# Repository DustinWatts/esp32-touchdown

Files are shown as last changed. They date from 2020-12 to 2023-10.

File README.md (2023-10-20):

# ESP32 TouchDown






## Where to buy?

Available from:

- Tindie: -> https://www.tindie.com/products/dustinwattsnl/esp32-touchdown/ (Ships from The Netherlands)

- Lectronz -> https://lectronz.com/products/esp32-touchdown (Ships from The Netherlands)

- Eplop Electornics -> https://store.eplop.co.uk/product/esp32touchdown/ (Ships from the UK)

- PCBWay -> https://www.pcbway.com/project/gifts_detail/ESP32_TouchDown.html (Ships from China) 

## FreeTouchDeck

#### Your ESP32 TouchDown comes with FreeTouchDeck pre-installed. Check out this simple start guide: [With FreeTouchDeck pre-installed](https://github.com/DustinWatts/esp32-touchdown/wiki/With-FreeTouchDeck-pre-installed)

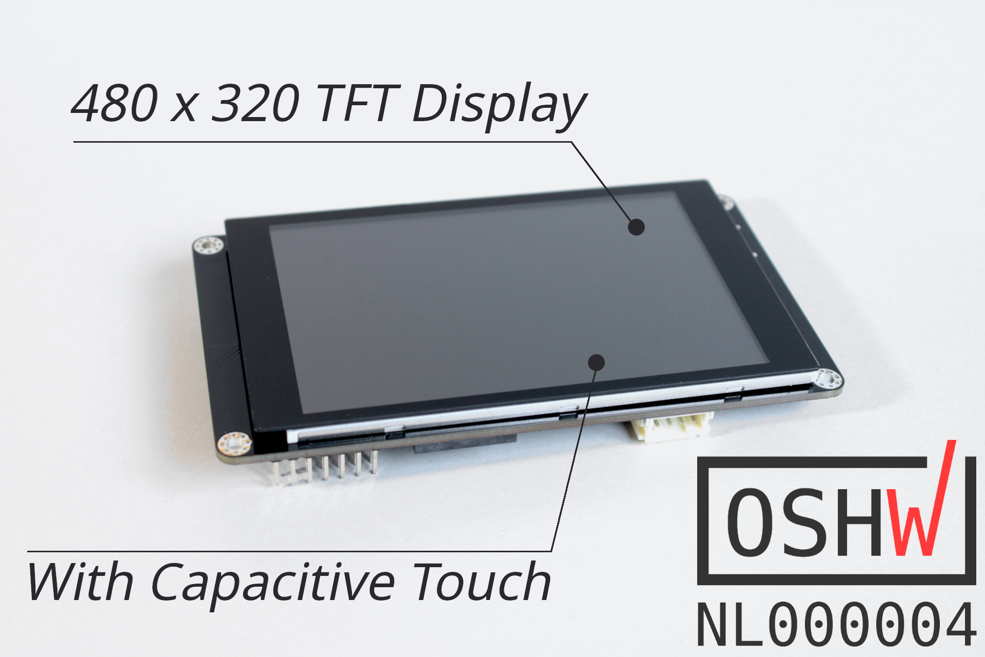
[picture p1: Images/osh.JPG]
ESP32 TouchDown


ESP32 TouchDown

While working on [FreeTouchDeck](https://github.com/DustinWatts/FreeTouchDeck), I really wanted to use capacitive touch. Unfortunately, most modules I could find were resistive touch and capacitive touch has a much nicer user experience. While I was designing, it made sense to put the ESP32 on the board itself, removing the need for an ESP32 Dev board. I wanted to take full advantage of the ESP32 wireless capabilities (Wifi, BLE) so I included a battery management circuit. ESP32 TouchDown can run off of a LiPo battery and also charge it. Here is a full list of the features:

- ESP32-WROOM-32D
- ILI9488 480*320 TFT screen in 4-wire SPI mode
- FT62x6 Capacitive Touch Controller
- APK2112 3.3V regulator _(On V1.1 of the board an AP7365 is used, see changelog.txt)_
- MCP73831 battery management IC _(On V1.1 of the board a Shouding SD8016 is used, see changelog.txt)_
- CP2102 USB-to-UART bridge
- USB-C connector
- microSD card holder
- Battery voltage divider connected to GPIO35
- Passive buzzer connected to GPIO26
- 12 unused GPIO's broken out
- Stemma / JST-PH I2C connector

ESP32 TouchDown works out of the box (as ESP32 Dev Module) with the Arduino IDE, providing you have installed the ESP32 Arduino Core. If you have not, this is where you can find it: [https://github.com/espressif/arduino-esp32](https://github.com/espressif/arduino-esp32).

## Documentation:

Documentation can be found in the [Wiki](https://github.com/DustinWatts/esp32-touchdown/wiki).

## TFT screen and touch controller

ESP32 TouchDown uses an 480x320 screen with an ILI9488 ([datasheet](https://github.com/DustinWatts/esp32-touchdown/blob/main/Hardware/Datasheets/ILITEK_ILI9488.pdf)) driver. There are numerous drivers out there, but I found TFT_eSPI by Bodmer the most versatile. [https://github.com/Bodmer/TFT_eSPI](https://github.com/Bodmer/TFT_eSPI). 

Pins used by the TFT screen are:

- GPIO2 -> DC_RS
- GPIO4 -> TFT_RESET
- GPIO15 -> TFT_CS
- GPIO18 -> SPI Clock
- GPIO23 -> SDI (MOSI)

The TFT backlight anode (positive supply) is selectable via a jumper on the back. You can either power it directly from 3.3V or use GPIO32. By default, the positive source is GPIO32. You can this pin and use PWM to control the backlight brightness.

_Note: On V1.1 of the board the jumpers used are with bridged pads. So by default have no solder blob. See changelog.txt_

TFT Backlight Select

The touch controller is a FocalTech FT62x6 ([datasheet](https://github.com/DustinWatts/esp32-touchdown/blob/main/Hardware/Datasheets/FT6236-FocalTechSystems.pdf)). The first batch uses an FT6236 and the second batch of boards has the FT6206. Both have the same I2C address of 0X38. I made an Arduino IDE library available here: [https://github.com/DustinWatts/FT6236](https://github.com/DustinWatts/FT6236). This library also supports the FT6202.

Pins used by the FT62x6 are:

- GPIO21 -> I2C data
- GPIO22 -> I2C clock
- GPIO27 -> IRQ

## GPIO Breakout

The following GPIO's are broken out on the header:

- GPIO 12
- GPIO 13
- GPIO 14
- GPIO 16
- GPIO 17
- SCK (GPIO 18, used as SPI clock)
- SDO (GPIO 19, used as SPI MOSI)
- SDA (GPIO 21, used as I2C data)
- SCL (GPIO 22, used as I2C clock)
- SDI (GPIO 23, used as SPI MISO)
- GPIO 33
- GPIO 34 (note: INPUT only!)

## SD Card

The following pins are used by the SD card holder:

- GPIO 25 --> CD/DAT3
- GPIO 23 --> CMD
- GPIO 18 --> CLK
- GPIO 19 --> DAT0

*CD (card detect) DAT1 and DAT2 are not connected.*

## Speaker (buzzer)

- GPIO 26

## Uploading code to the ESP32 TouchDown

For FreeTouchDeck installation instructions see: https://github.com/DustinWatts/FreeTouchDeck/wiki/1.-Installation

For other code: The ESP32 TouchDown uses the same configuration as an ESP32 Dev Module. So you can use those board definitions to upload your own code to the ESP32 TouchDown:
Arduino IDE board settings

## Open Source

Everything about the ESP32 TouchDown is open source. This means I provide you will all the designs I make. In this repository, you will find the KiCad project, including schematic, and board layout. Also, the complete BOM is available to you. I have included the datasheets of all the hardware used.

<div style="margin:0 auto;">
  
  <div> 
    License&nbsp;&nbsp;&nbsp;&nbsp;&nbsp;&nbsp;&nbsp;&nbsp;&nbsp;&nbsp;&nbsp;&nbsp;&nbsp;&nbsp;&nbsp;&nbsp;&nbsp;&nbsp;
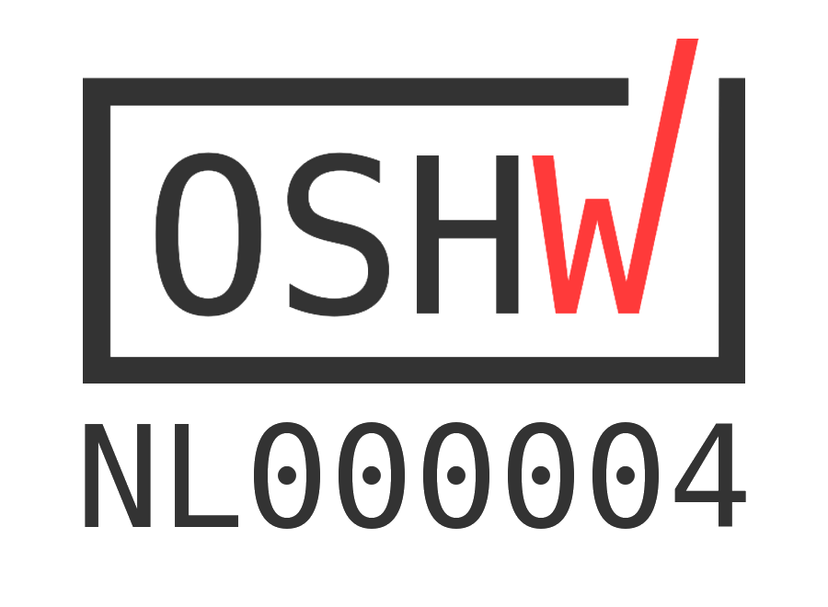
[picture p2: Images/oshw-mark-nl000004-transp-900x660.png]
OSHW
    
  </div>

</div>

## Support Me

If you like what I am doing, there are a number of ways you can support me. 

| Platform | Link|
|:-----:|:-----|
| [Twitter](https://twitter.com/dustinwattsnl "Follow me on Twitter") | You can follow me on Twitter: [@dustinwattsnl](https://twitter.com/dustinwattsnl "Follow me on Twitter")|
| [YouTube](https://www.youtube.com/dustinwatts "Subscrive to my YouTube channel") | You can subscribe to my channel on Youtube: [/dustinWatts](https://www.youtube.com/dustinwatts "Subscribe to my YouTube channel") |
| [Patreon](https://www.patreon.com/dustinwatts) | You can support me by becoming a patron on Patreon: https://www.patreon.com/dustinwatts |
| [PayPal.me](https://www.paypal.me/dustinwattsnl) | You can make a one time donation using PayPal.me: https://www.paypal.me/dustinwattsnl |

## Help

For quick access to help you can join my Discord server where I have a dedicated #esp32-touchdown channel. https://discord.gg/RE3XevS

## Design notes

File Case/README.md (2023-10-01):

# The Case

The case for the ESP32 TouchDown comes in two parts. The front is the same for every style of case you want. The back comes in four variants; a flush cover, a cover with a battery compartment, a back that has the same wedge style as [FreeTouchDeck](https://github.com/DustinWatts/FreeTouchDeck), and a similar style but at an angle of 30°.

You will also find the .f3z file so you can import the case in Fusion360 and modify it to your liking. 
The file called "ESP32_TouchDown_Case_with_Grid.f3z" contains the front with a 2*3 grid.

# The Front
This part is the same for all.
ESP32 TouchDown
(file: ESP32_TouchDown_Front.stl)
# The Flush Back
With four holes for mounting.
ESP32 TouchDown
(file: ESP32_TouchDown_Flush.stl)
# The Battery Back
Which comfortably fits a 2000mAh battery.
ESP32 TouchDown
(file: ESP32_TouchDown_Battery.stl)
# The FreeTouchDeck-style Back
Like the case for FreeTouchDeck.
ESP32 TouchDown
(file: ESP32_TouchDown_FTD.stl)
# The 30° angled FreeTouchDeck-style Back
Like the case for FreeTouchDeck but at an angle of 30°.
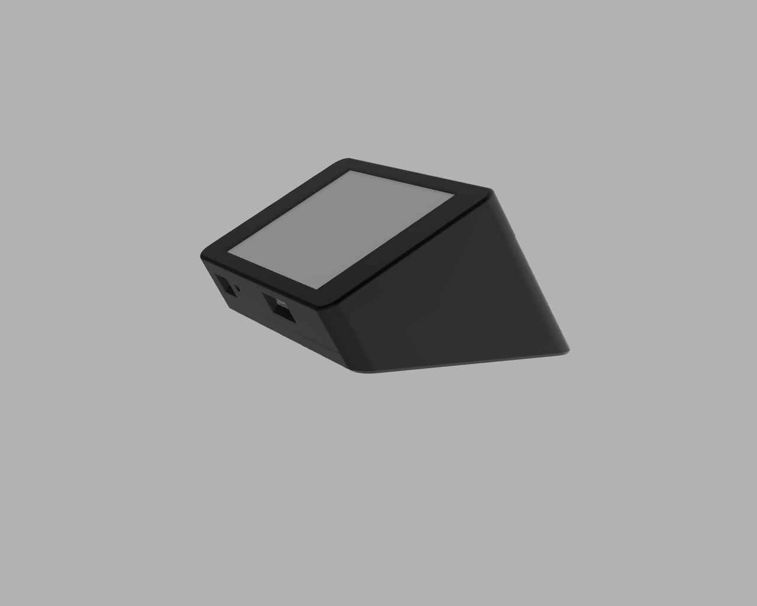
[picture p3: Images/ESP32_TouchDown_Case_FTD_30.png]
ESP32 TouchDown

(file: ESP32_TouchDown_FTD_30.stl)
# The Grid Style Front
A front that has a 2*3 grid.
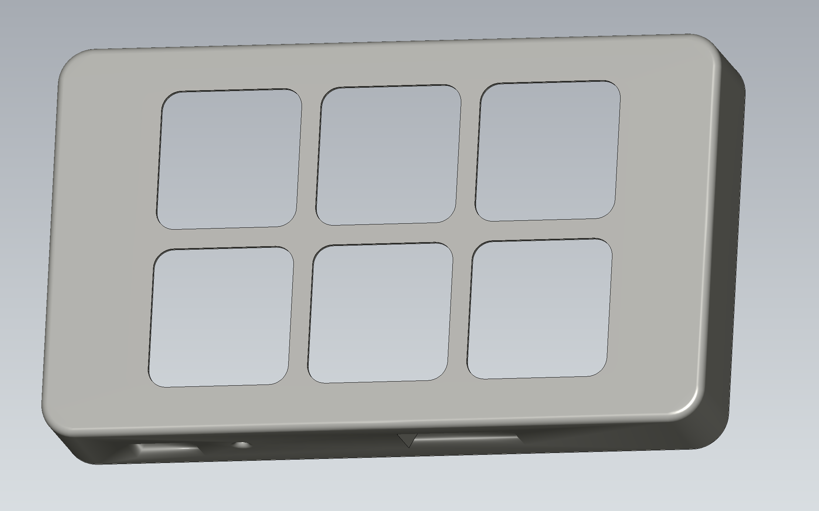
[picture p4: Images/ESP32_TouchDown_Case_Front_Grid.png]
ESP32 TouchDown

(ESP32_TouchDown_Front_Grid.stl)
# More cases on Thingiverse

Also check out the cases made by ESP32 TouchDown users:  https://www.thingiverse.com/search?q=esp32+touchdown

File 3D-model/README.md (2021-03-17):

# ESP32 TouchDown 3D Model

Fusion360 Model, obj and step file to help you design your own case!

### Fusion360 Model:
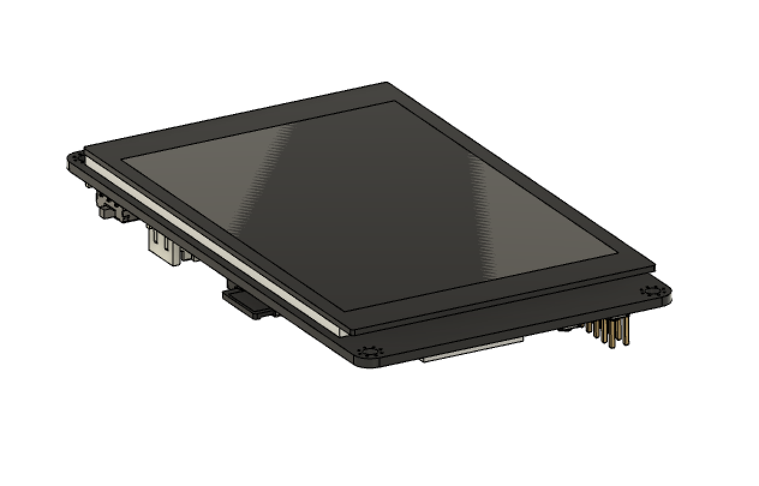
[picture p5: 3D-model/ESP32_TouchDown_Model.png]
ESP32 TouchDown 3D Model


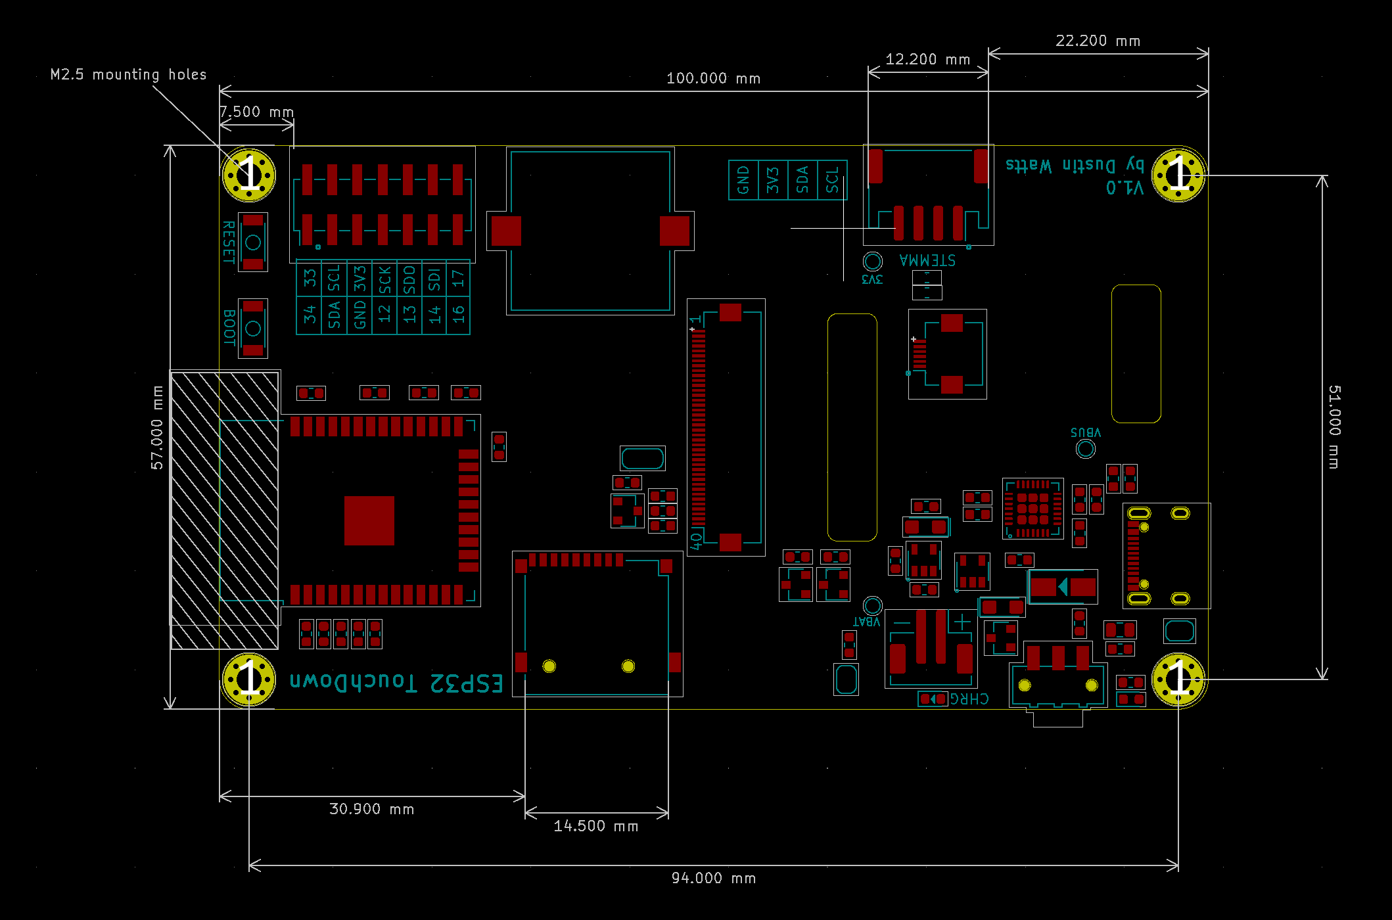
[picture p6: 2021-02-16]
Hardware/ESP32_TouchDown_dimensions.png

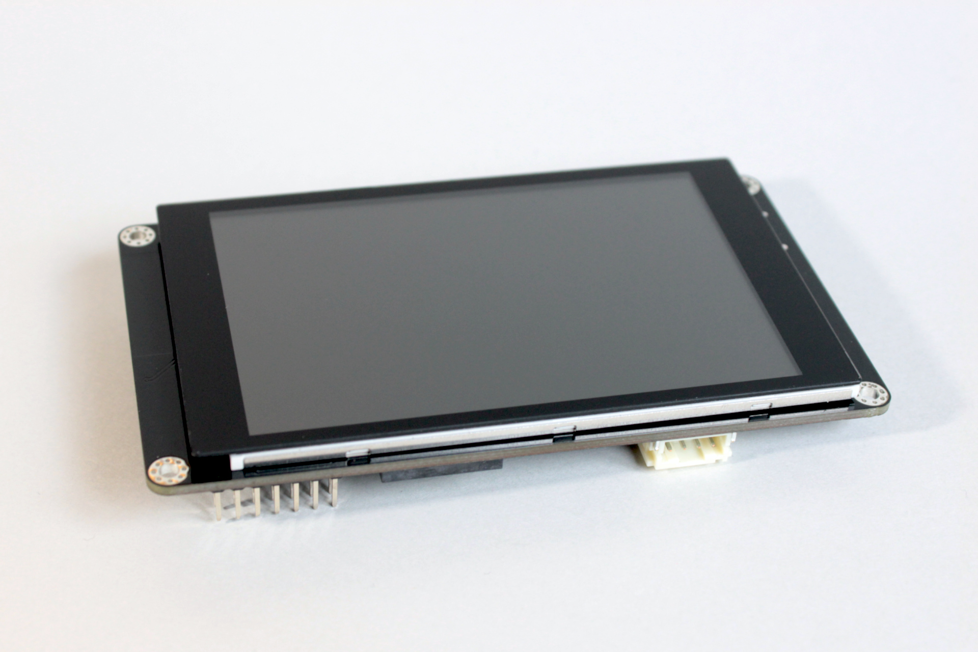
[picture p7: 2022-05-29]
Images/no_overlay.JPG

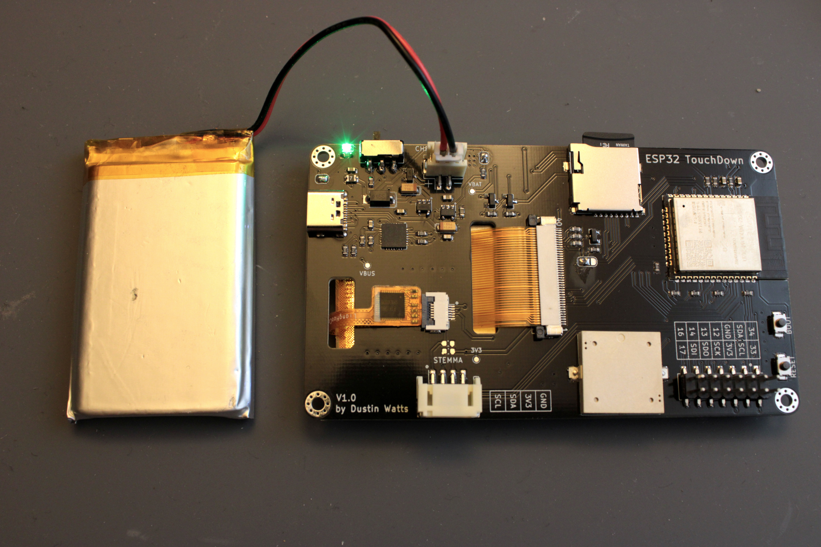
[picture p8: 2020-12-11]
Images/ESP32_TouchDown_1.jpg

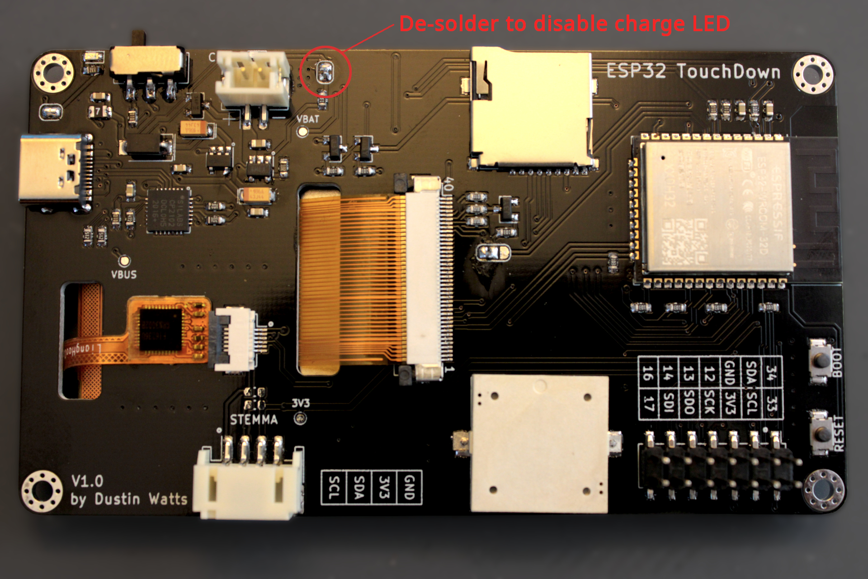
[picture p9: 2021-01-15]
Images/ESP32_TouchDown_Charge_LED.jpg

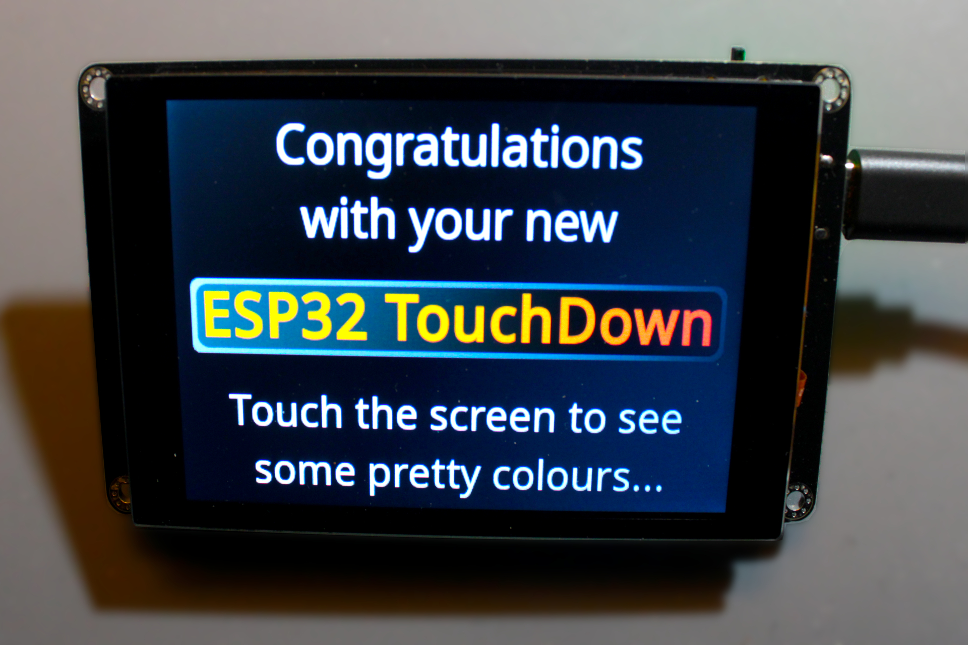
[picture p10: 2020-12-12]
Images/ESP32_TouchDown_2.jpg

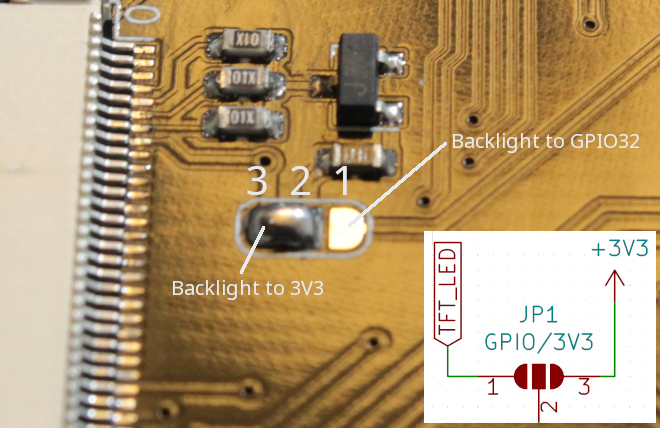
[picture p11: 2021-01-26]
Images/TFT_Backlight_select.jpg

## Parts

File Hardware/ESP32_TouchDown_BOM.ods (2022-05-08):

Item Nr. | Quantity | Ref** | Value | Footprint | Nr. Pads | Manufacturer | Manufacture Part Number | Description | LCSC Part Number
1 | 1 | U4 | * | SMD-38 | 38 | Espressif | ESP32-WROOM-32D | ESP32 | C473012
2 | 1 | U1 | * | QFN-28 5x5x05P | 28 | Silicon Labs | CP2102-GMR | USB to Serial IC | C6568
3 | 1 | F1 | 1.5A 200ms | 0805 | 28 | Littelfuse | 0805L075WR | PTC Fuse | C151146
4 | 1 | U5 | * | SOT-23-5 | 5 | Microchip Technology | MCP73831T-2ACI/OT | LiPo Charging IC | C424093
5 | 1 | U3 | * | SOT-23-5 | 5 | Diodes Inc. | AP2112K-3.3TRG1 | 3.3V regulator | C51118
6 | 1 | SD1 | * | SMD | 13 | Korean Hroparts Elec | TF-01A | microSD card holder | C91145
7 | 3 | Q1, Q2, Q4 | * | SOT-23-3 | 3 | LGE | S8050 | NPN Transistor | C402279
8 | 1 | SW3 | * | SMD | 3 | Korean Hroparts Elec | K3-1280S-F1 | On/Off Slide Switch | C92658
9 | 1 | Q3 | * | SOT-23-3 | 3 | Diodes Inc. | DMG3415U-7 | VBUS/VBATT PNP MOSFET | C96616
10 | 1 | FPC2 | * | P=0.5mm | 8 | JUSHUO | AFC01-S06FCC-00 | FPC Connector for CTC (Bottom Contact) | C262262
11 | 1 | FPC1 | * | P=0.5mm | 42 | JUSHUO | AFC07-S40ECC-00 | FPC Connector for TFT (Top Contact) | C11097
12 | 1 | J5 | * | SMT | 12 | XKB Connectivity | U262-16XN-4BVC11 | USB-C Connector | C319148
13 | 1 | J3 | * | SMD, P=2mm | 42 | JST | B2B-PH-SM4-TB(LF)(SN) | Battery Connector | C160352
14 | 2 | SW1, SW2 | * | SMD, 3x4x2.5mm | 2 | SHOU HAN | TS-1088R-02526 | Tactile button | C455281
15 | 1 | D1 | * | SMA(DO-214AC) | 2 | ST(Semtech) | SS14D | Schottky Diode | C83912
16 | 2 | C4,C5 | 10uF | 3216 | 2 | AVX | TAJA106K010RNJ | 10uF 3216 Tantalum Capacitor | C7177
17 | 1 | LS1 | * | SMD, 16x16x2.5mm | 2 | INGHAi | GSC1625YB-3V4000 | Piezo buzzer | C255335
18 | 1 | J4 | * | SMD, P=2mm | 6 | JST | S4B-PH-SM4-TB(LF)(SN) | Stemma Connector | C265102
19 | 1 | J2 | * | SMD, P=2.54mm | 14 | BOOMELE(Boom Precision Elec) | C84004 | Pin Header 2x7 SMD | C84004
20 | 5 | C1, C2, C6, C8, C10 | 100nF | 0603 | 2 | Jelly Bean | n/a | 0.1uF Ceramic Capacitor
21 | 1 | C7 | 1uF | 0603 | 2 | Jelly Bean | n/a | 1uF Ceramic Capacitor
22 | 1 | C9 | 10uF | 0603 | 2 | Jelly Bean | n/a | 10uF Ceramic Capacitor
23 | 1 | R13 | 1.3K | 0603 | 2 | Jelly Bean | n/a | 1.3K 0603 Resistor
24 | 2 | R3, R4 | 1K | 0603 | 2 | Jelly Bean | n/a | 1K 0603 Resistor
25 | 2 | Rprog1, R22 | 3.3K | 0603 | 2 | Jelly Bean | n/a | 3.3K 0603 Resistor
26 | 1 | R1 | 4.7K | 0603 | 2 | Jelly Bean | n/a | 4.7K 0606 Resistor
27 | 9 | R5, R6, R7, R8, R10, R11, R12, R18, R23 | 10K | 0603 | 2 | Jelly Bean | n/a | 10K 0603 Resistor
28 | 2 | R24, R25 | 5.1K | 0603 | 2 | Jelly Bean | n/a | 5.1K 0603 Resistor
29 | 4 | R2, R9, R14, R15 | 100K | 0603 | 2 | Jelly Bean | n/a | 100K 0603 Resistor
30 | 1 | D3 | Blue, Vf=3.2V | 0603 | 2 | Jelly Bean | n/a | 0603 LED Blue
31 | 1 | D2 | Green, Vf=2.8V | 0603 | 2 | Jelly Bean | n/a | 0603 LED Green
 | Alternate parts
 |  | Q3 | * | SOT-23-3 | 3 | PJSEMI | PJM3415PSA | VBUS/VBATT PNP MOSFET | C411717
 |  | LS1 | * | SMD, 16x16x2.5mm | 2 | KELIKING | KLJ-1625 | Piezo buzzer | C201041
 |  | U3 | * | SOT-23-5 | 5 | Diodes Inc. | AP7365-33WG-7 | 3.3V regulator | C150742
 |  | U5 | * | SOT-23-5 | 6 | Shouding | SD8016 | LiPo Charging IC | C250808
 |  | Total number SMD pads | 282
 |  | Total number TH pads | 4

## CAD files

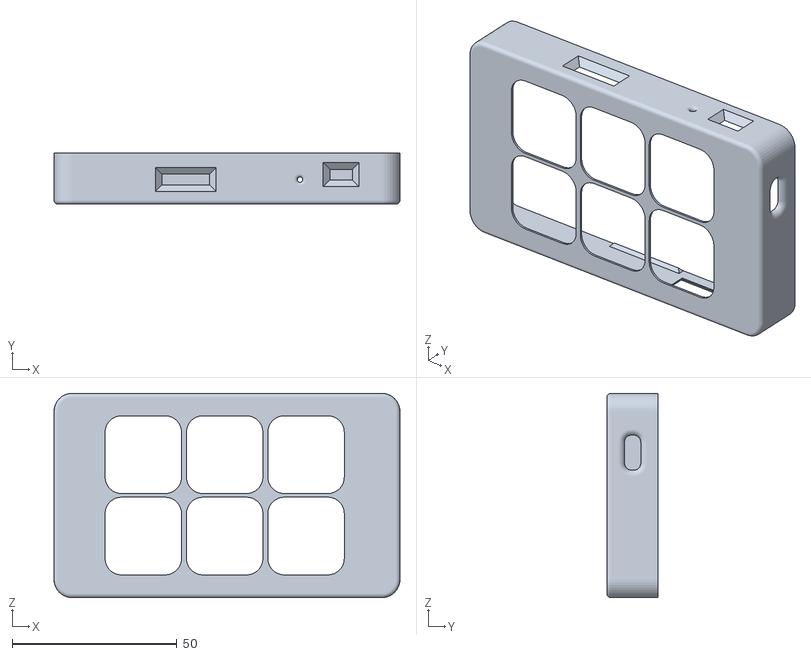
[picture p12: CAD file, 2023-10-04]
Case/ESP32_TouchDown_Front_Grid.stl
105.0 x 15.6 x 62.0

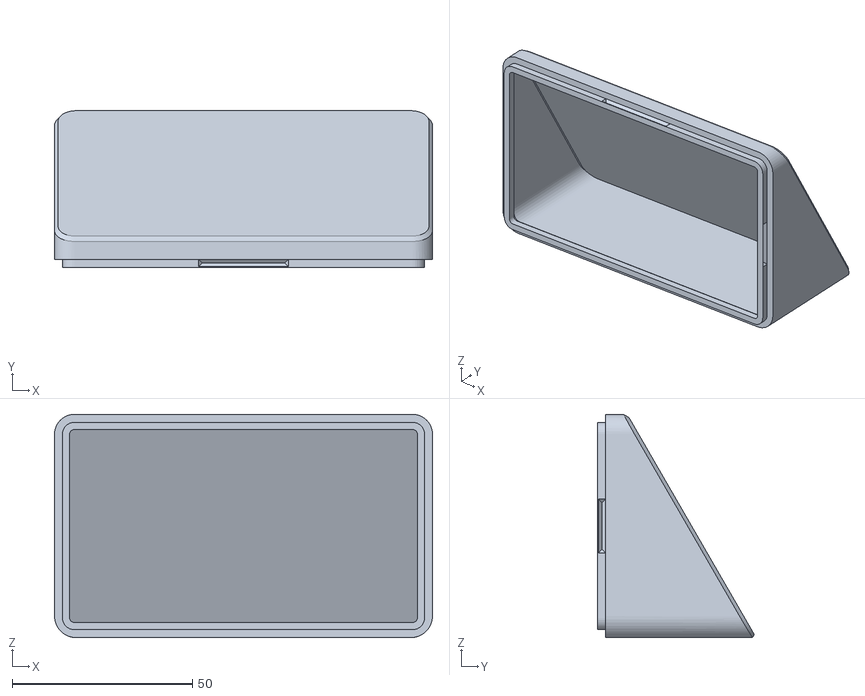
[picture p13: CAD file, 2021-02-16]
Case/ESP32_TouchDown_Back_FTD_30.stl
105.0 x 43.5 x 62.0

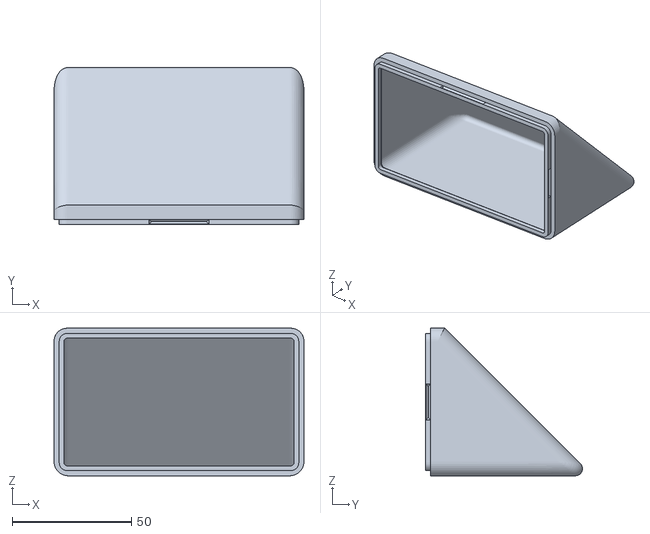
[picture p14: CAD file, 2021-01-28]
Case/ESP32_TouchDown_Back_FTD.stl
105.0 x 65.9 x 62.0

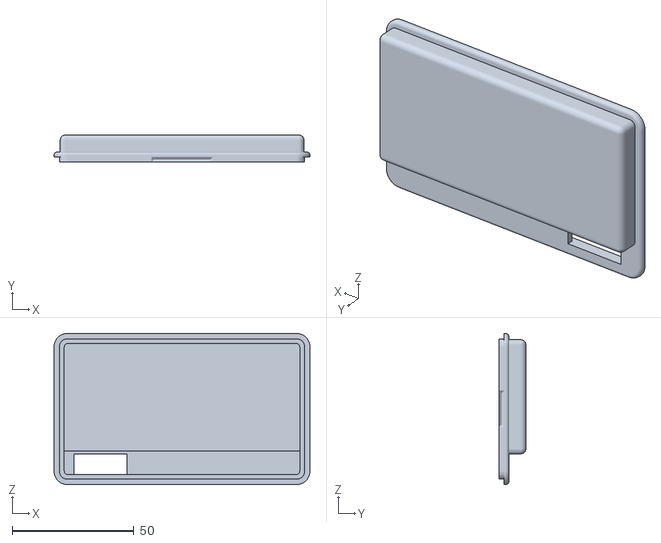
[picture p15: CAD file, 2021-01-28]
Case/ESP32_TouchDown_Back_Battery.stl
105.0 x 11.0 x 62.0

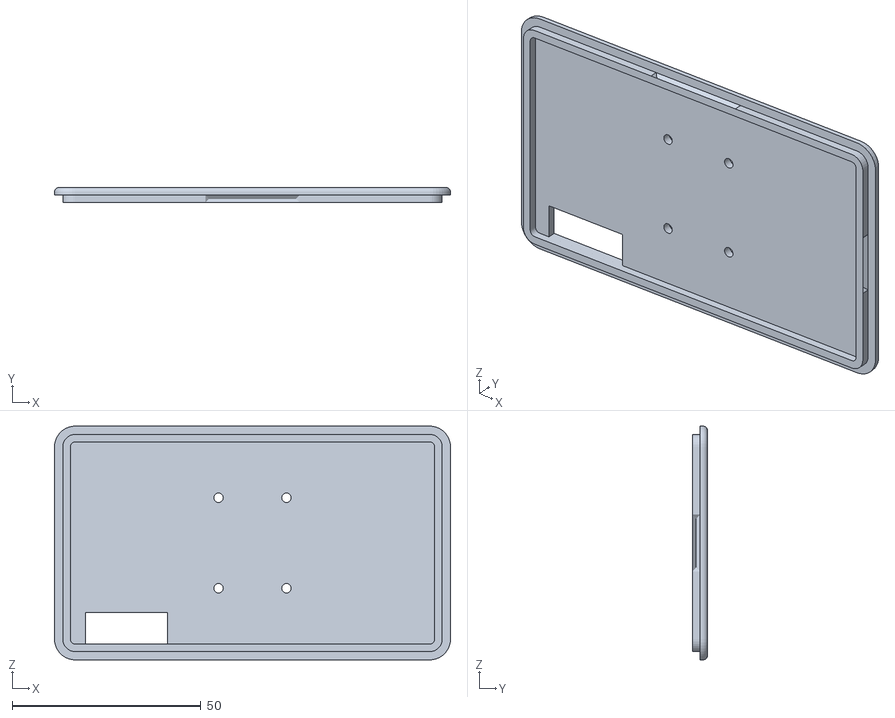
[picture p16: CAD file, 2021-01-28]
Case/ESP32_TouchDown_Back_Flush.stl
105.0 x 4.00 x 62.0

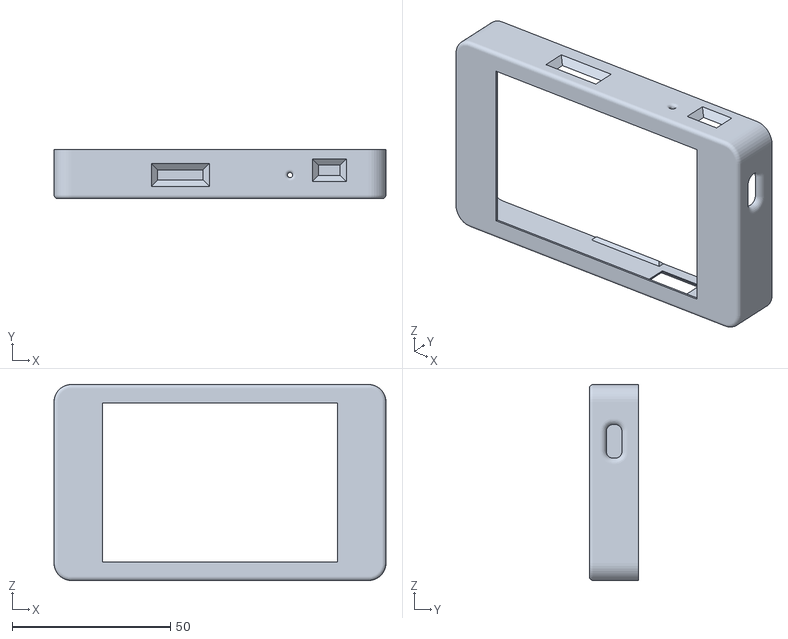
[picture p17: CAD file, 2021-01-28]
Case/ESP32_TouchDown_Front.stl
105.0 x 15.6 x 62.0

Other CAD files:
3D-model/ESP32_TouchDown_Model.f3d

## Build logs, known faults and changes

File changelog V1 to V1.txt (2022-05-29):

ChangeLog

ESP32 TouchDown V1.0 VS ESP32 TouchDown V1.1

- Changed Jumpers to pre-bridged pads (connected without solderblob)
	So if you want to disable the ON and CHARGE LED, you will have to cut the trace and if you want to change the TFT backlight from GPIO32 to fixed 3.3V you will have to cut the trace and put a solderblob from the middle pad to the other pad.

- MCP73831 Battery management IC changed to Shouding SD8016 (pin compatible)
- AP2112K Voltage regulator changed to AP7365 (pin compatible)

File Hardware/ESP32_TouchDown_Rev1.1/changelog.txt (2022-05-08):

Changelog ESP32 TouchDown

Rev 1.1

- Changed Jumpers to pre-bridged pads (connected without solderblob)

- MCP73831 Battery management IC changed to Shouding SD8016 (pin compatible)

- AP2112K Voltage regulator changed to AP7365 (pin compatible)

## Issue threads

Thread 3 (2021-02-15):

Where to buy aka Crowdfunding?

JanHBade, 2021-02-15:
Hello,

are they any plans to make a batch of full function pcbs? or a crowdfunding project?

Not everyone have the skill to make a one board?

fwahl711, 2021-02-15:
would be interested as well. maybe tindie?

DustinWatts, 2021-02-15:
Hi @JanHBade The idea is for me to sell them on Tindie indeed. Hackaday was a bit early with discovering the ESP32 TouchDown. I made a batch and sold them to a few people to get some feedback. I'm currently working on a batch to put up on Tindie, I hope later this week!

fwahl711, 2021-02-15:
hey @DustinWatts thanks for the fast reply! looking forward to it :) On the upside of early discovery, you can probably make 10-20x of what u planned originally ...

glennswest, 2021-02-15:
I would love to use these to make cnc countroller. Let me know and I will buy a few.

K1rdro, 2021-02-15:
I'd like to buy a couple as well, depending on the price.

danielo515, 2021-02-17:
Another interested here

DustinWatts, 2021-02-17:
Yesterday I put the Tindie listing up. https://www.tindie.com/products/dustinwattsnl/esp32-touchdown/

It seems I highly underestimated interest and it sold out within 10 minutes. Off course I am making more, but to get a bit of an idea of how many more to make, you can join the waitlist.

danielo515, 2021-02-17:
Thanks for the link. Joined!

On Wed, Feb 17, 2021 at 7:19 AM Dustin Watts <notifications@github.com>
wrote:

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

--
---
https://danielorodriguez.com

Closed 2021-07-03.

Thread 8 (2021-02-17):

Please add BOM entry for the TFT

zapta, 2021-02-17:
Thanks for sharing your design.  I couldn't find the TFT you are using in the BOM. Can you please add it with model number or a link to a vendor?

(By TFT I mean the entire TFT subassembly, not just the TFT or touch controller ICs).

Thanks.

hagbardZ, 2021-03-11:
The same problem here ... couldnt find the TFT :-(
Could you please add a link, where to find it ?

DustinWatts, 2021-03-15:
Hi @zapta and @hagbardZ sorry for the late reaction. The screens are sold under all kinds of part numbers. But I did find them on AliExpress, if you search for "ILI9488 ft6236" you can find them. I wish I could make it easier and give you a part number but it takes some searching.

Make sure the pinout described matches that of the FPC connector of the screen and touch controller:
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

There are two types. One with a short flex PCB with the touch controller and one with a long one. You will need the one with the SHORT flex PCB:

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

Closed 2021-07-03.

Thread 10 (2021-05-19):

Case models in STEP format?

Snowflake6, 2021-05-19:
Is there any chance the case models could be posted in STEP or IGES or perhaps Solidworks native format?

(Solidworks doesn't like working with STL files.)  It's not a showstopper to have to start from scratch but it would be nice to have a starting point for designing a new case.

DustinWatts, 2021-07-03:
https://github.com/DustinWatts/esp32-touchdown/tree/main/3D-model Contains a .step model of the ESP32 TouchDown

Closed 2021-07-03.

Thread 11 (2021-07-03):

Battery recomendations

pjratl, 2021-07-03:
any suggested battery and or wiring?

DustinWatts, 2021-07-03:
Hi @pjratl any protected single cell LiPo (3.7V) will work. As to wiring, the ESP32 TouchDown uses a JST-PH (2.0mm pitch) connector. The + and - are marked on the board, so make sure that matches you battery. Make sure you don't plug in the battery with a reversed polarity! If you battery comes with the wrong polarity, you can swap the pins on the battery connector by pulling the pins out and putting them back in the header in the correct orientation.

As to capacity, I recommend getting at least 2000mAh. This will give you about 10 hours of continues use. More off course if you use the sleep function.

rastagraffix, 2022-07-01:
What size is the cutout in the battery back? It would be helpful to mention this in the README.

DustinWatts, 2022-07-02:
> What size is the cutout in the battery back? It would be helpful to mention this in the README.

At around 3.55V/3.6V (depending on V1.0 or V1.1 of the ESP32 TouchDown) the voltage regulator stops regulating down to 3.3V. There will still be output an output voltage on the LDO but it will be unregulated. This also depends on the current draw. With a lower current draw the dropout of the regulator is lower.

The ESP32 will operate (according to the datasheet) with a minimum of 3.0V. To be on the safe side, I recommend a minimum battery voltage of 3.6V that will make sure the ESP32 TouchDown works according to what is expected.

rastagraffix, 2022-07-02:
No, I was asking what the physical size of the battery cutout is.

DustinWatts, 2022-07-03:
Ah... I confused cutout with cutoff :)

It is 95 x 43 mm.

DustinWatts, 2022-12-20:
@danielo515 Thanks for sharing!

DustinWatts, 2023-03-15:
I will edit the README.md to reflect the size of the battery compartment on the battery case, and will add some information that will inform people that any single cell LiPo with a protection circuit will work. But it is very important to check that the polarity of the battery connector matches that of the connector on the board!

Closed 2023-03-15.

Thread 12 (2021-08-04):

FLASH from PlatformIO requires BOOT+RESET buttons?

bradanlane, 2021-08-04:
I am trying to load new firmware to the Touchdown using PlatformIO. I have not tested with Arduino IDE.

The only way I can get it to flash is to use the BOOT and RESET buttons. Is this normal / expected ?

DustinWatts, 2021-08-05:
Technically there is an auto-reset circuit that should do it for you. But the BOOT and RESET buttons are there so you can also do it manually.

All ESP32 TouchDown that are sent out are tested with the AUTO RESET function so maybe it is something in PlatformIO?

bradanlane, 2021-08-05:
The BOOT button was broken on my unit and I replaced it. This button now works (which is good since I must always use it). I do not believe there is any difference in the way PlatformIO operates. I will attempt to test the behavior of the "auto reset" circuit.

DustinWatts, 2022-05-08:
This has been stale for a while, so I'm closing it.

Closed 2022-05-08.

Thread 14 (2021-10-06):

KiCad footprints folder is incomplete

OhmSchool, 2021-10-06:
Hi there,
Fantastic project!  Due to worldwide product shortages, I would like to replace several hardware components and print a customized PCB using substitute parts which I have in stock.  However KiCad folder only contains 4 of the 24+ total footprints in your PCB file:

Hirose_FH12-40S-0.5SH_1x40-1MP_P0.50mm_Horizontal_flipped.kicad_mod
INGHAi GSC1625YB-3V4000.kicad_mod
microSD_TF-01A-C91145.kicad_mod
TS-1088R-02526.kicad_mod

Would it be possible for you to update the following folder to include all KiCad footprints (.pretty folder)?

esp32-touchdown/Hardware/ESP32_TouchDown_Rev1/ESP32_TouchDown_lib.pretty/

Thank you and Kind Regards

DustinWatts, 2021-10-06:
Hmm... I would have thought that because all other footprints are default KiCad footprints that they would be in there. Did you install the KiCad libraries? Let me check what happens on a fresh install of KiCad... If that doesn't work, I will put all the footprints in a local library.

DustinWatts, 2023-03-15:
Since the last activity in this issue is over 16 months ago, I'm closing this issue.

Closed 2023-03-15.

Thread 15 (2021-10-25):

White Screen?

odesired, 2021-10-25:
Hi Dustin,

love the design and the idea.

I bought all the products you recommended, pcb from pcbway ILI9488 screen and ESP32-WROOM-32D and ive followed your youtube tutorial https://www.youtube.com/watch?v=s2X4BQ9VmEU&t=515s&ab_channel=DustinWatts.

I've got an issue which im sure is on my end with my config.

I have a white screen it strobes a little bit my user_setup.h is exactly as the video any suggestions on how to fix?

DustinWatts, 2022-05-08:
I assume this issue is resolved after so many months, so closing it.

Cerbere14, 2024-08-11:
Bonjour
impossible de faire la calibration l'écran reste figé sur Touch corners as indicated
ILI9341_DRIVER
merci

Closed 2022-05-08.

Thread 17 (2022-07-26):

Screw size for mounting holes

markusressel, 2022-07-26:
Hey there, awesome project!

Sorry for the dumb question... but what is the recommended screw size for the four (4) mounting holes on the corners of the PCB (both diameter & length) when using the printable cases located within this repo?

I tried to find the info in this repo and on Tindie but wasn't able to find it anywhere :cry:

Thx!

DustinWatts, 2022-07-26:
Hi Mark! You can find it here: https://github.com/DustinWatts/esp32-touchdown/blob/main/Hardware/ESP32_TouchDown_dimensions.png

But maybe there is a more obvious place to mention it. Maybe in the README.md... I'll update that with some dimensions.

Closed 2022-07-26.

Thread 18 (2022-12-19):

boards.txt on mac is on a very nasty path

danielo515, 2022-12-19:
It is on `/Users/{user}/Library/Arduino15/packages/arduino/hardware/avr/{version}/boards.txt`
Maybe it is worth updating the wiki

DustinWatts, 2022-12-19:
Yeah. The boards.txt thing is really not necessary as you can just select the ESP32 DevKit V1. So there is no use for it.

danielo515, 2022-12-19:
> Yeah. The boards.txt thing is really not necessary as you can just select the ESP32 DevKit V1. So there is no use for it.

OH really? I missed that part on the docs

DustinWatts, 2023-03-15:
baords.txt is removed from the repo.

Closed 2023-03-15.

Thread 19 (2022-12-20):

rotation or flip?

danielo515, 2022-12-20:
Hello!
Is there a way to set the rotation of the screen in the config? I have mine mounted in a stand that will require it to be flipped vertically.

Thanks!

DustinWatts, 2022-12-20:
Hi @danielo515 Not in the current -master version. You can set in the code though. If you re-upload the code without re-uploading the SPIFFS, your config will be fine!

DustinWatts, 2023-03-15:
Quick update. On the next version of FreeTouchDeck which is based on the -development branch. Rotation is a option as a setting. Currently working on getting the configurator right and then it will be released.

danielo515, 2023-03-17:
Awesome. Thanks for the update

On Wed, Mar 15, 2023 at 6:26 PM Dustin Watts ***@***.***>
wrote:

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

--
---
https://danielorodriguez.com

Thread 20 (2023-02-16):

SPI port configuration issues

Michelebuffa, 2023-02-16:
I followed your tutorial to configure the pins of the Esptouchdown as follows :
#define TFT_BL 32 //TFT_LED
#define TFT_MISO 19 //SDO
#define TFT_MOSI 23 //SDI
#define TFT_SCLK 18 //SCK
#define TFT_CS 15 //TFT_CS
#define TFT_DC 2 //DC_RS
#define TFT_RST 4 //TFT_RESET
#define TOUCH_CS 21 //I2C SDA
#define SCL_I2C 22 //I2C SCL

I tried to install an example you attached to the repository, but it just comes up with a "gray screen" like in the picture.
So I tried to use the Arduino_GFX library which allows you to create a software SPI and the result does not change.
Where am I doing wrong ?

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

DustinWatts, 2023-02-16:
Hi @Michelebuffa Did it work when it arrived? I mean did it ever work? I check all screens before I ship.

Michelebuffa, 2023-02-18:
I see that you have included a setup file for your card in the TFT_eSPI library,
https://github.com/Bodmer/TFT_eSPI/blob/master/User_Setups/Setup204_ESP32_TouchDown.h
therefore I attempted to edit the User_Setup and User_Setup_Select files, roughly following your example directions. These are the files I'm using:

[Setup204_ESP32_TouchDown.txt](https://github.com/DustinWatts/esp32-touchdown/files/10773604/Setup204_ESP32_TouchDown.txt)
[User_Setup.txt](https://github.com/DustinWatts/esp32-touchdown/files/10773606/User_Setup.txt)
[User_Setup_Select.txt](https://github.com/DustinWatts/esp32-touchdown/files/10773607/User_Setup_Select.txt)

DustinWatts, 2023-02-18:
Back to my other question, did it work when you first powered it up? All ESP32 TouchDown's are tested and are shipped with FreeTouchDeck on them.

Michelebuffa, 2023-02-18:
No screen appeared when first turned on !

Michelebuffa, 2023-02-18:
It should just be a library problem, since the screen backlight works!

DustinWatts, 2023-02-18:
Well... not really because the it could be that the screen is broken or the connection is bad. So backlight works but SPI not.

On the back of the TouchDown there is a large FPC (flat cable) connector. Try and open it with the two black locking devices (be careful not to break it) and take out the FPC cable. Puh it in again as far as it will go and close the two black locking devices again This to make sure the screen makes a good connection to the board.

Michelebuffa, 2023-02-18:
I'll try and let you know!

Michelebuffa, 2023-02-18:
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

Michelebuffa, 2023-02-18:
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

DustinWatts, 2023-02-18:
Make sure to push both black locks in!

Michelebuffa, 2023-02-18:
I closed the connector, reconnected the board to the power supply and .......
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

DustinWatts, 2023-02-18:
I saw one of the black locks not quite closed. Is it now?

Michelebuffa, 2023-02-18:
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

Michelebuffa, 2023-02-18:
If you can't get the display to work, I always have a wireless "touch pad" wireless lol

DustinWatts, 2023-02-18:
Yeah that looks good now. Try using the webinstaller one more time, because in there (in that binary) the pins are configured correctly. Be sure to use the ESP32 TouchDown version.

If that does not work, I am confident enough to say either the screen broke, or the connector. Then, message me the details of your purchase (ordernumber, and where you bought it) to dustin_watts@yahoo.com and I will see what I can do to get you a working ESP32 TouchDown.

Michelebuffa, 2023-02-18:
I try again with the web installer, in case I send you an email.

Michelebuffa, 2023-02-18:
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

How to leave feedback today, I'll give you 6 out of 5 stars for your patience!

DustinWatts, 2023-02-18:
Well a review where you bought it is always appreciated ;)

Anyway, email me and we will get you a working ESP32 TouchDown!

Michelebuffa, 2023-02-18:
I'll send you the email with all the details of the order. Thanks so much for your assistance.

DustinWatts, 2023-02-18:
Great, I will wait for your email. I will close this issue for now. But will update it with my findings about the screen later. You can always reopen it off course!

Closed 2023-02-18.

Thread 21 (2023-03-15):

Touch function not working

HaViGit, 2023-03-15:
Hi Dustin. A while ago I bought your TouchDeck and it worked out of the box including touch controls. I am now trying to install something else and have tested with ESP32_TouchDown_Drawing.ino and ESP32_TouchDown_Keyboard.ino. The sketches compile without errors and start up fine, but the touch function does not work. The touch library (https://github.com/DustinWatts/FT6236) is installed correctly so that shouldn't be a problem. Can you help me? Regards, Hans.

DustinWatts, 2023-03-15:
Hi HaViGit!

I think you mean TouchDown, but that's ok I understand ;) Could you try it with the example from the FT6236 library called: [simple_touch.ino](https://github.com/DustinWatts/FT6236/blob/main/examples/simple_touch/simple_touch.ino)? That is the most basic touch sketch/test there is.

Also have a look at the output of the serial monitor to see if any errors, show up. If you test it with the example I pointed you to above, also please post the output between the serial monitor (pay attention! That script still outputs serial data on 9600 so you might need to change it. This will be fixed in the new release)?

If you put the output of the serial monitor between thee back ticks (```) before the first line and the last line it will make it better readable, like this:

```
X Coordinate: 24
Y Coordinate: 267
X Coordinate: 24
Y Coordinate: 271
etc...
etc...
etc...
```

You could also check if the little 6 pin FPC connector still makes a good connection to the smaller FPC board, this is used for touch and might have some loose.

HaViGit, 2023-03-15:
Thanks for your quick response. You are probably right with the correct name, I must have been mistaken. For me it's just a very nicely designed piece of hardware that I'm happy with ;-)

The sketch simple_touch.ino works and shows the coordinates in the serial monitor. So far so good... The sketch ESP32_TouchDown_Drawing.ino shows the text "Start touching to start drawing." on the display but there is no response to touch, neither on the display nor in the serial monitor. Same with ESP32_TouchDown_Keyboard.ino, the keyboard is shown but no output on the screen or in the serial monitor.

I've checked the connector, it seems fine but otherwise simple_touch.ino might not have worked either I think. Hopefully you have some suggestions.

HaViGit, 2023-03-15:
Not sure if this is important but below the content of my current User_Setup.h file:

```// User Setup for the ESP32 TouchDown V1.0 and V1.1
// ILI9488 using 4-wire SPI and using an FT6206 touch controller

#define USER_SETUP_ID 204

#define ILI9488_DRIVER

#define TFT_BL   32
#define TFT_BACKLIGHT_ON HIGH

#define TFT_MISO 19
#define TFT_MOSI 23
#define TFT_SCLK 18
#define TFT_CS   15
#define TFT_DC    2
#define TFT_RST   4

#define TOUCH_CS 21

#define LOAD_GLCD
#define LOAD_FONT2
#define LOAD_FONT4
#define LOAD_FONT6
#define LOAD_FONT7
#define LOAD_FONT8
#define LOAD_GFXFF

#define SMOOTH_FONT

#define SPI_FREQUENCY  27000000
#define SPI_READ_FREQUENCY  20000000
#define SPI_TOUCH_FREQUENCY  2500000

DustinWatts, 2023-03-15:
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

Since the example from the FT6236 library works, maybe some of my sketches broke. I will have to check the sketches and see if they work on my end.

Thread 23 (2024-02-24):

Problems using User_Setup.h

HaViGit, 2024-02-24:
Hi Justin. Can you help me use your ESP32 TouchDown V1.0? I am unable to get any output on the screen, I am using version 2.5.34 of the TFT_eSPI library and in the library folder (../libraries/TFT_eSPI) I have replaced the file User_Setup.h with yours (see link below). Compilation runs without error messages but there is no output on the screen. I hope to hear from you.

https://raw.githubusercontent.com/DustinWatts/esp32-touchdown/main/Examples/TFT_eSPI%20Setup%20Example/User_Setup.h

Closed 2024-02-24.

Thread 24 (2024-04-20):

Examples broken

JsGraaf, 2024-04-20:
The examples are broken due to the removal of
'''
#define TFT_BACKLIGHT_ON HIGH // Level to turn ON back-light (HIGH or LOW)
'''

Currently, the screen remains empty since the TFT_BL pin defaults to LOW. Maybe add a simple PWM function to give the user an idea of how to handle the brightness of the backlight such as:
'''
void TFT_SET_BL(uint8_t Value)
{
  if (Value < 0 || Value > 100)
  {
    Serial.println("Error setting TFT Backlight level");
  }
  else
  {
    analogWrite(TFT_BL, Value * 2.55);
  }
}
''' (Modified from https://github.com/Bodmer/TFT_eSPI/issues/142)

Another solution would be to inform them that they are responsible for enabling the backlight.

DustinWatts, 2024-04-20:
Ah... that has changed in a newer version. I'll update the User_Setup.h example immediately.

About the black dimming. That is already in the code a on the TFT screen under "Settings".

JsGraaf, 2024-04-21:
Thank you!

Closed 2024-04-21.

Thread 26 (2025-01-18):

examples request: backlight

kmaher9, 2025-01-18:
hey is there any chance we can get an example for changing backlight please? I have a button hooked up and want to "turn the screen off" when it is pressed, and back on when the button state changes. Thanks!

DustinWatts, 2025-01-19:
It is not quit clear what you want to achieve. Because there is already a sleep function that does this. You could put the code for this function as a button in a menu. And  then the ESP32 goes toe sleep immediately And wakes up when you touch the screen.

And for that the code is:
```
esp_sleep_enable_ext0_wakeup(touchInterruptPin, 0);
esp_deep_sleep_start();
```
Else I might have misunderstood you question...

kmaher9, 2025-01-20:
sorry I was opening on the back of the user you replied to here - https://github.com/DustinWatts/esp32-touchdown/issues/24

I don't want to sleep the esp, just turn the screen off and on with a button press, specifically just the screen off is that possible? thanks

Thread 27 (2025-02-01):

None of the examples works with the display

jgj-risma, 2025-02-01:
I had the preinstalled demo code working just fine I could see everything just fine in the display.
I then uploaded one of the Examples, and now I just get a black screen.

I can see that tough events works because I can see in the serial communication that it registeres this.
Also the examples are note updated to the latest LEDC. I.e. ledcsetup no longer exists its ledcattach

How can I get the display to light up?

DustinWatts, 2025-02-02:
Hi @jgj-risma You closed the topic yourself. I presume this means it is no longer an issue?

What I can tell you is that ledc has changed since the latest update, so downgrading the Arduino ESP32 core should fix the problem while I work on a fix. On that works for all versions of the ESP32 Core.

jgj-risma, 2025-02-02:
Thanks for replying though I closed it.
Yes, very embarrasing, if I just red the comments I would have seen that I needed to set the user config. I managed to get the new ledc library to work on in the example also.

Closed 2025-02-01.

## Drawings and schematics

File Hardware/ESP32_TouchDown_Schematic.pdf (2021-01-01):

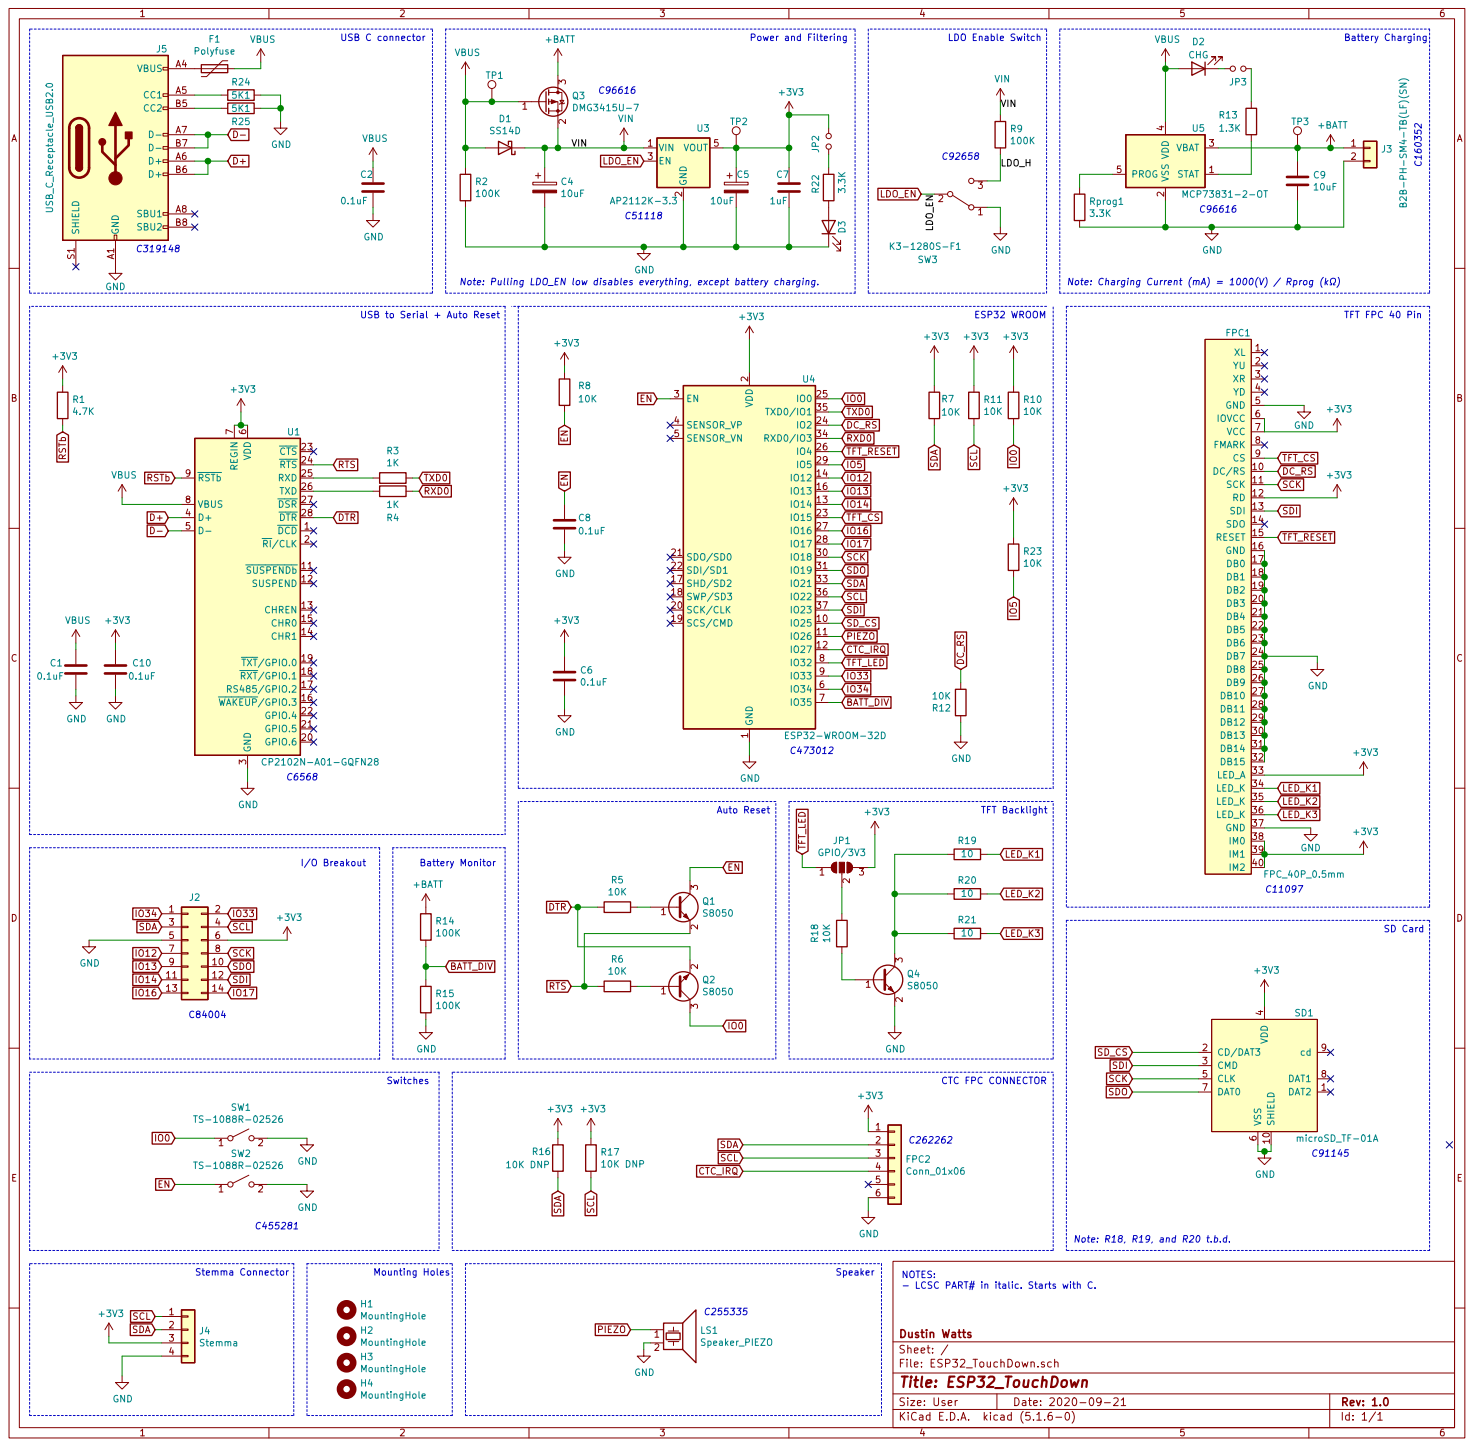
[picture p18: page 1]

+BATT GND GND GND

USB to Serial + Auto Reset
BATT_DIV DTR

2 SCK/CLK 20 SDO/SD0 21 SDI/SD1 22

File: ESP32_TouchDown.sch Sheet: / Dustin Watts

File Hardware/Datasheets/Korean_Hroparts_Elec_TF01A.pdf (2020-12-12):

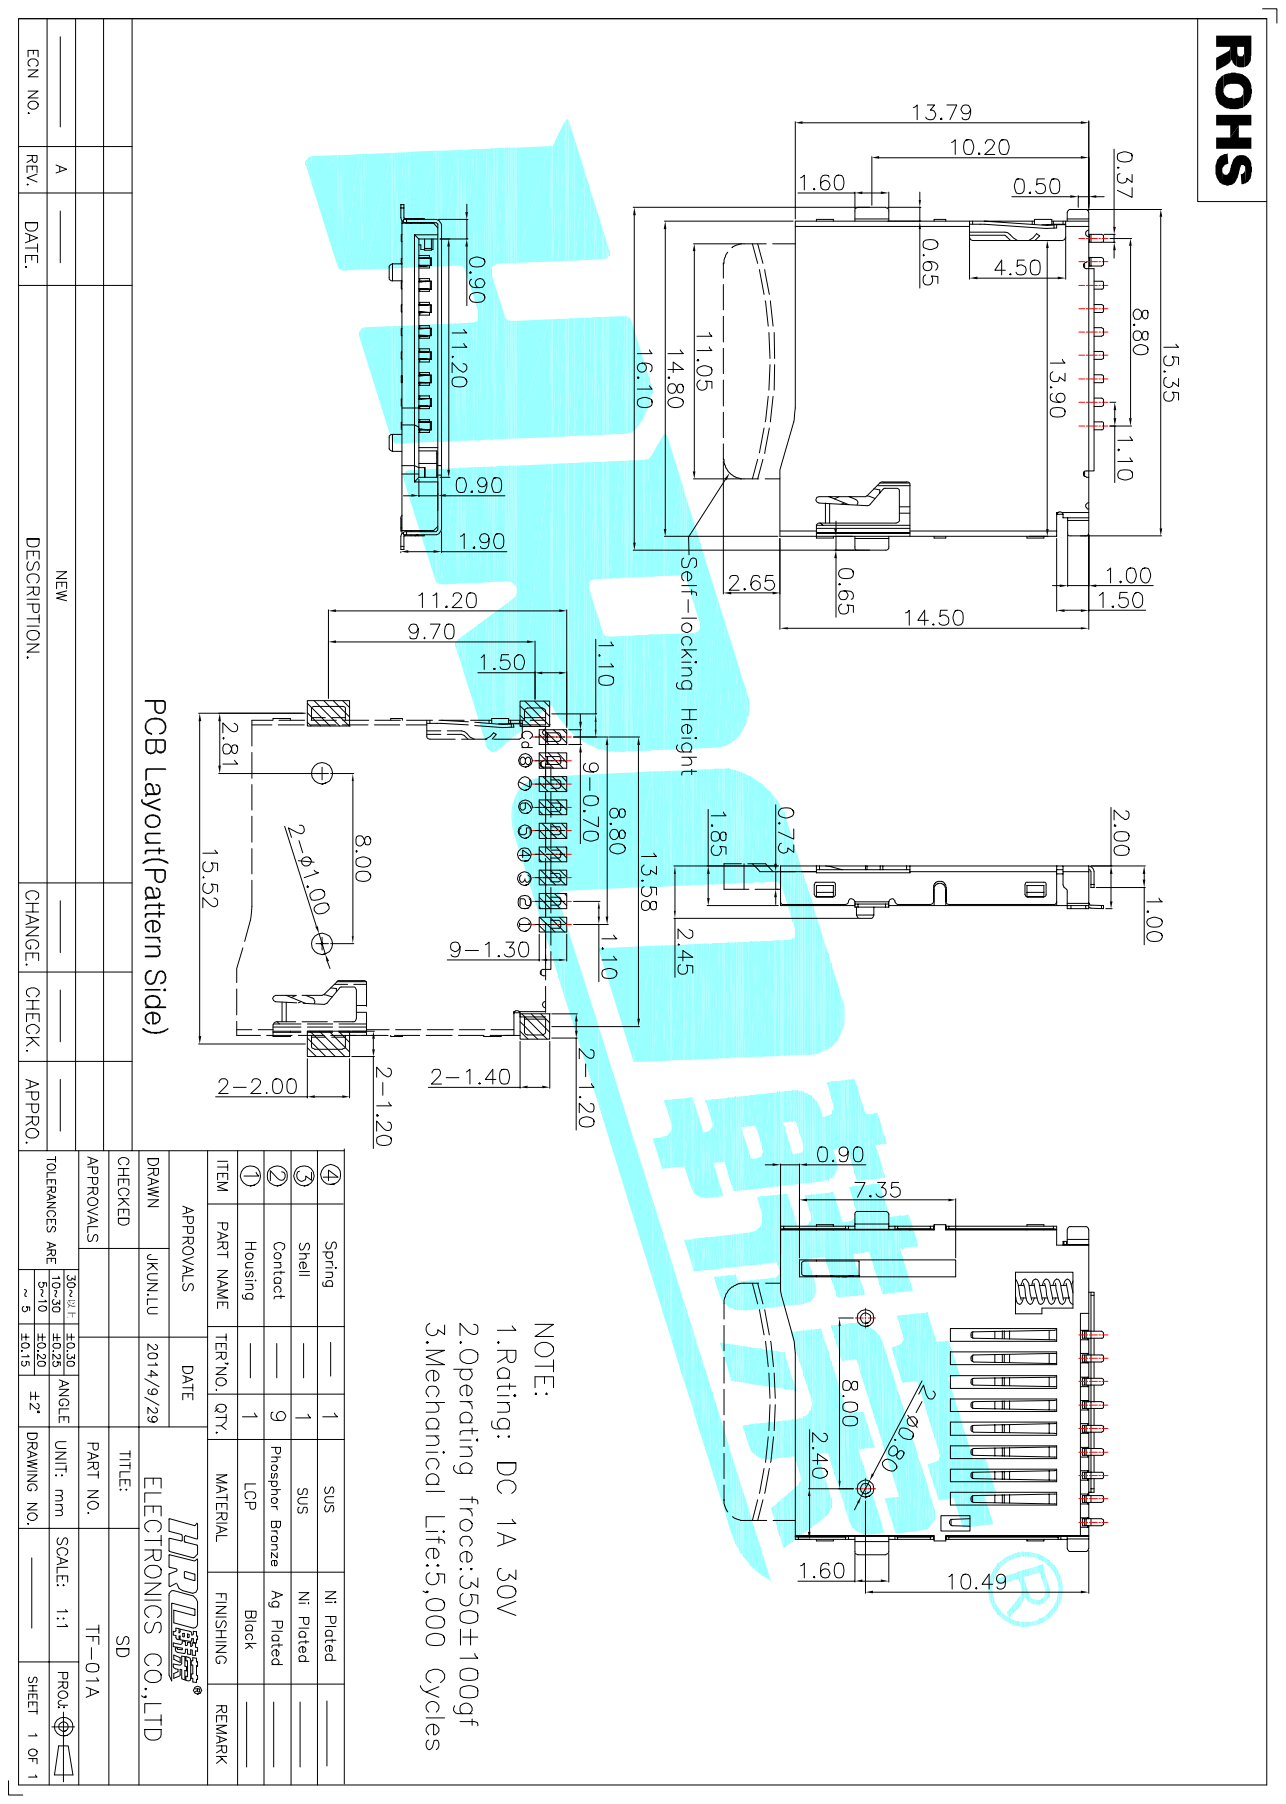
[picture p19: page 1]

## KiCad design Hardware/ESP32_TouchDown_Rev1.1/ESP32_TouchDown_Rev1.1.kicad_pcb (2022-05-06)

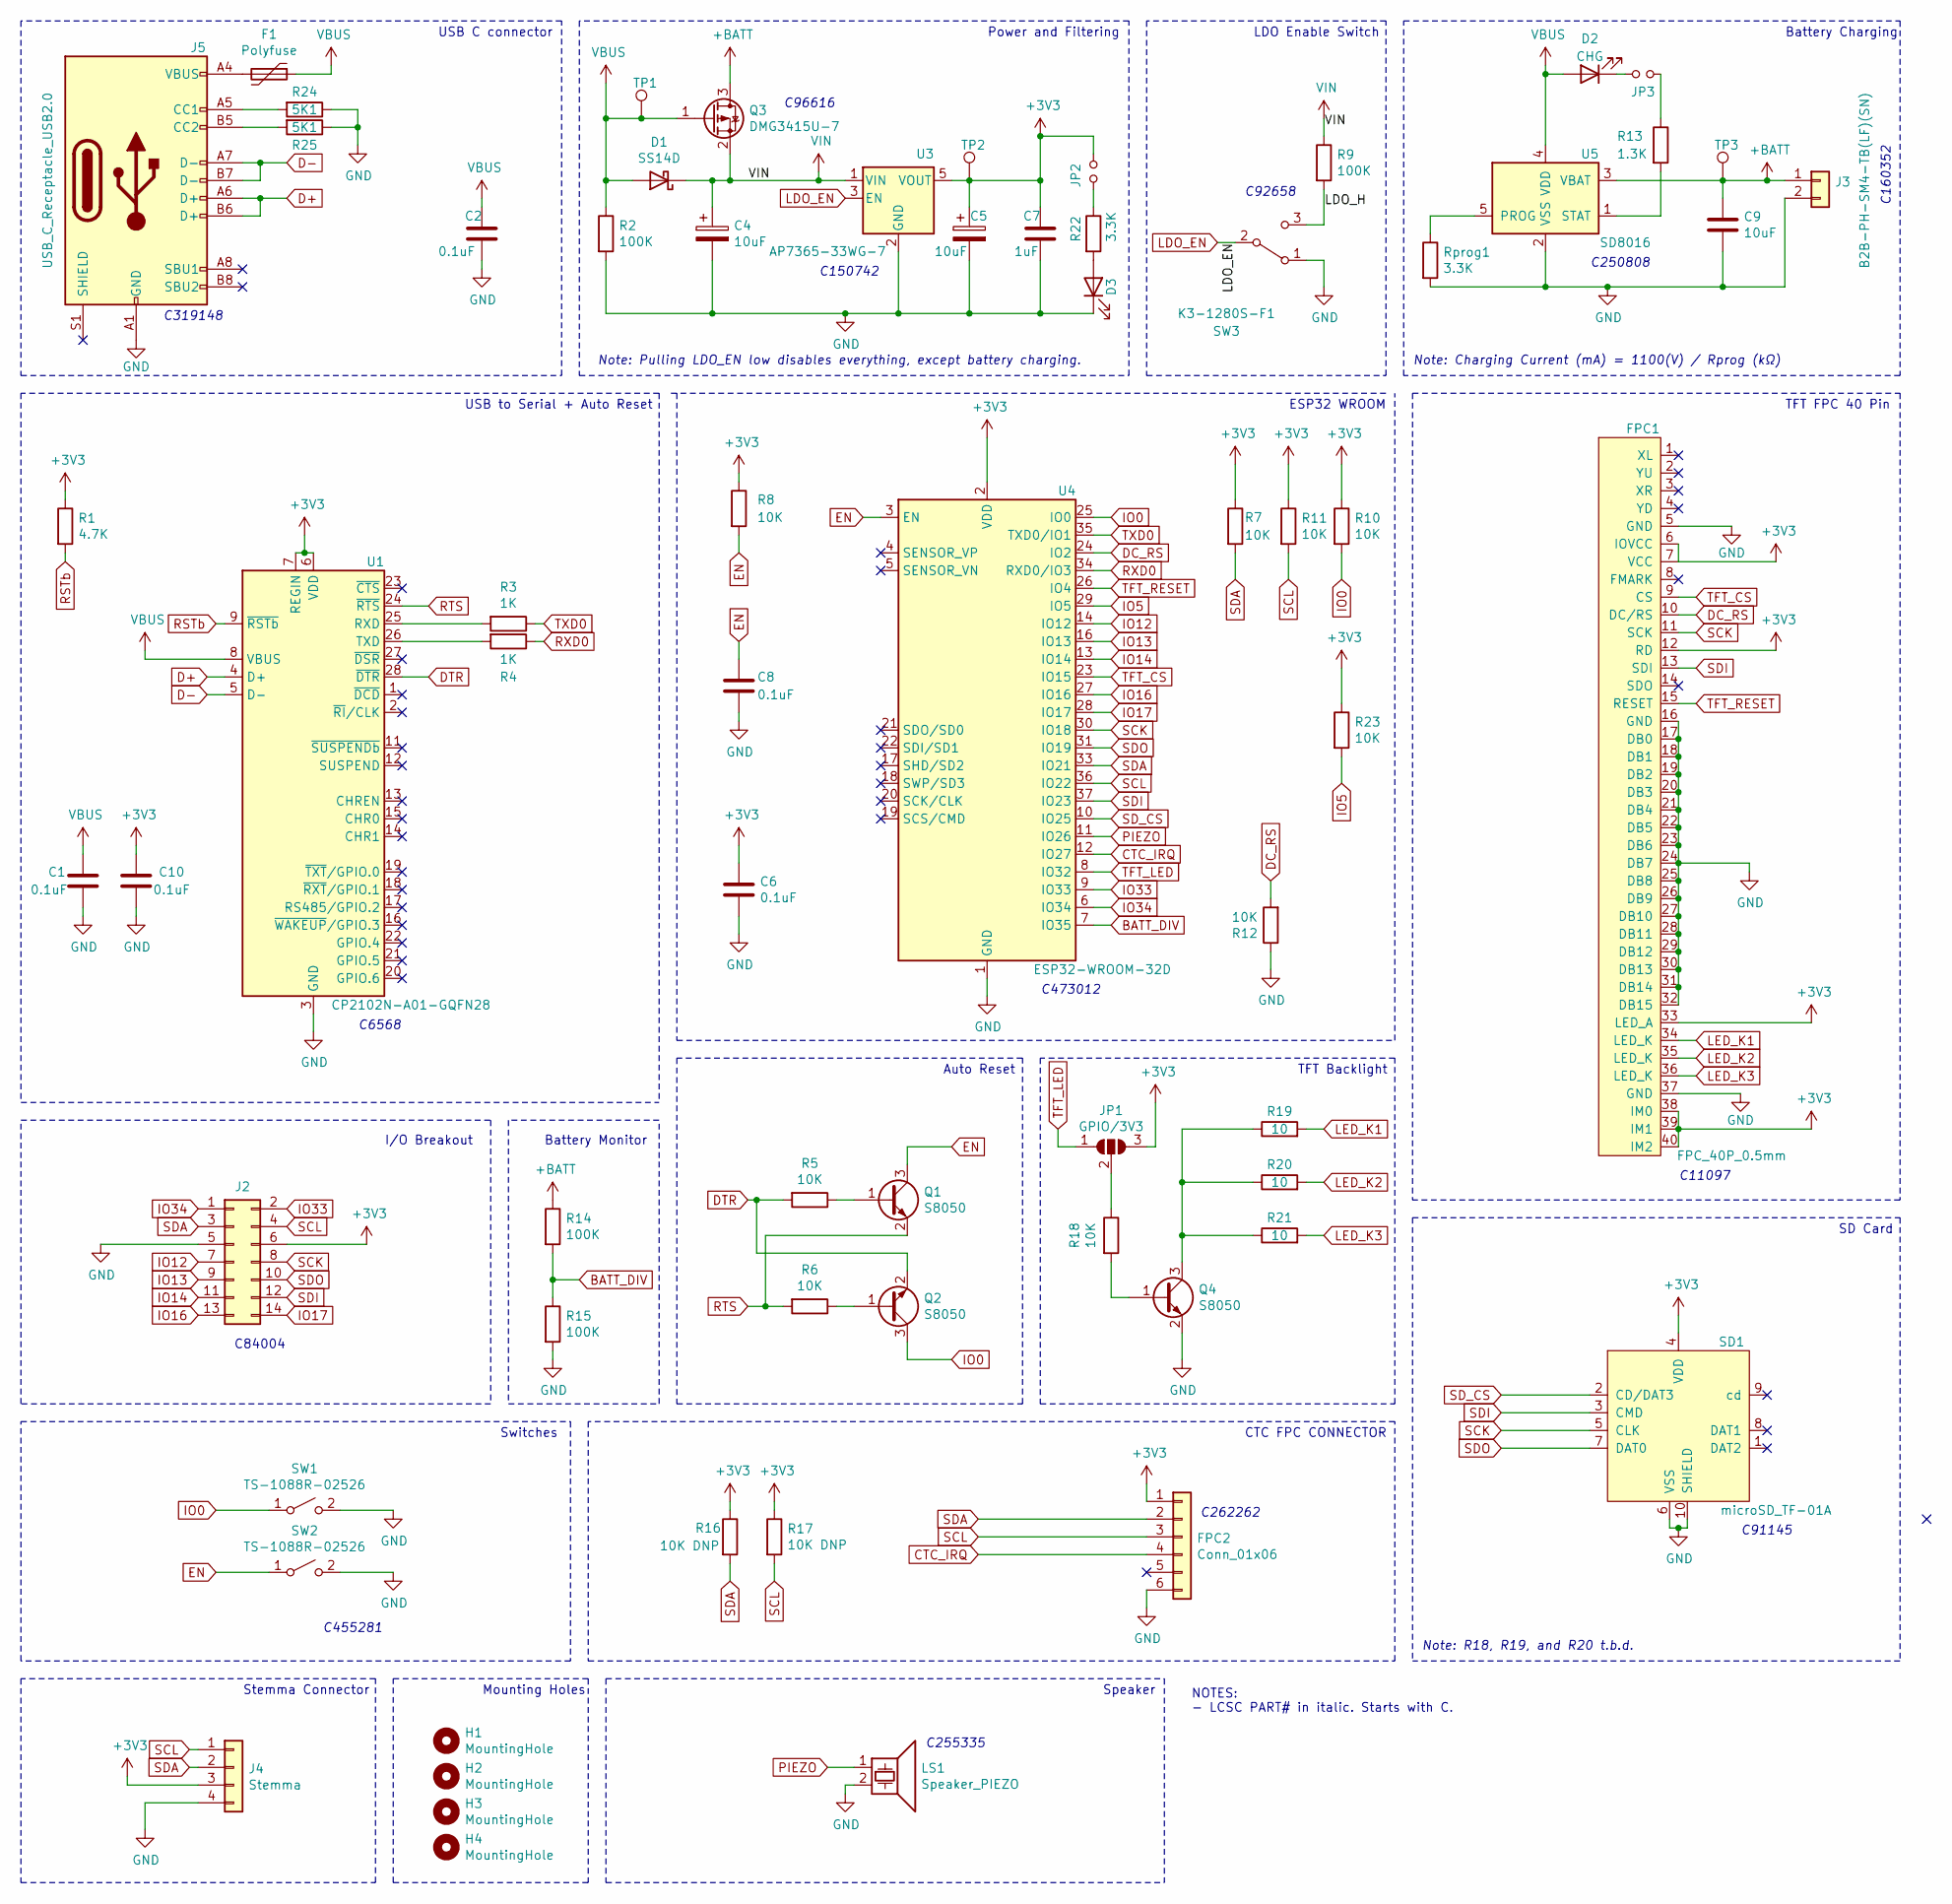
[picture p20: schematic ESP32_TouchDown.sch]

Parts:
C1, C2, C6, C8, C10: 0.1uF; C_0603_1608Metric
C4, C5: 10uF; CP_EIA-3216-18_Kemet-A
C7: 1uF; C_0603_1608Metric
C9: 10uF; C_0603_1608Metric
D1: SS14D; D_SMA
D2: CHG; LED_0603_1608Metric
D3: ON; LED_0603_1608Metric
F1: Polyfuse; Fuse_0805_2012Metric
FPC1: FPC_40P_0.5mm; Hirose_FH12-40S-0.5SH_1x40-1MP_P0.50mm_Horizontal
FPC2: Conn_01x06; Hirose_FH12-6S-0.5SH_1x06-1MP_P0.50mm_Horizontal
H1, H2, H3, H4: MountingHole; MountingHole_2.5mm_Pad_Via
J2: Conn_02x07_Odd_Even; PinHeader_2x07_P2.54mm_Vertical_SMD
J3: B2B-PH-SM4-TB(LF)(SN); JST_PH_B2B-PH-SM4-TB_1x02-1MP_P2.00mm_Vertical
J4: Stemma; JST_PH_S4B-PH-SM4-TB_1x04-1MP_P2.00mm_Horizontal
J5: USB_C_Receptacle_USB2.0; USB_C_Receptacle_XKB_U262-16XN-4BVC11
JP1: GPIO/3V3; SolderJumper-3_P1.3mm_Open_RoundedPad1.0x1.5mm_NumberLabels
JP2, JP3: Jumper_NO_Small; SolderJumper-2_P1.3mm_Open_RoundedPad1.0x1.5mm
LS1: Speaker_PIEZO; INGHAi GSC1625YB-3V4000
Q1, Q2, Q4: S8050; SOT-23
Q3: DMG3415U-7; SOT-23
R1: 4.7K; R_0603_1608Metric
R2, R9, R14, R15: 100K; R_0603_1608Metric
R3, R4: 1K; R_0603_1608Metric
R5, R6, R7, R8, R10, R11, R12, R18, R23: 10K; R_0603_1608Metric
R13: 1.3K; R_0603_1608Metric
R16, R17: 10K DNP; R_0603_1608Metric
R19, R20, R21: 10; R_0603_1608Metric
R22: 3.3K; R_0603_1608Metric
R24, R25: 5K1; R_0603_1608Metric
Rprog1: 3.3K; R_0603_1608Metric
SD1: microSD_TF-01A; microSD_TF-01A-C91145
SW1, SW2: TS-1088R-02526
SW3: K3-1280S-F1; SW_SPDT_CK-JS102011SAQN
TP1, TP2, TP3: TestPoint; TestPoint_Pad_D1.0mm
U1: CP2102N-A01-GQFN28; QFN-28-1EP_5x5mm_P0.5mm_EP3.35x3.35mm
U3: AP7365-33WG-7; SOT-23-5
U4: ESP32-WROOM-32D; ESP32-WROOM-32
U5: SD8016; SOT-23-5

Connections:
+3V3: C5.1, C6.1, C7.1, C10.1, FPC1.6 (IOVCC), FPC1.7 (VCC), FPC1.12 (RD), FPC1.33 (LED_A), FPC1.38 (IM0), FPC1.39 (IM1), FPC1.40 (IM2), FPC2.1, J2.6, J4.3, JP1.3 (B), JP2.2, R1.1, R7.1, R8.1, R10.1, R11.1, R16.1, R17.1, R23.1, SD1.4 (VDD), TP2.1, U1.6 (VDD), U1.7 (REGIN), U3.5 (VOUT), U4.2 (VDD)
+BATT: C9.1, J3.1, Q3.3 (D), R14.1, TP3.1, U5.3 (VBAT)
/LDO_H: R9.2, SW3.3 (C)
/VIN: C4.1, D1.1 (K), Q3.2 (S), R9.1, U3.1 (VIN)
BATT_DIV: R14.2, R15.1, U4.7 (IO35)
CTC_IRQ: FPC2.4, U4.12 (IO27)
D+: J5.A6 (D+), J5.B6 (D+), U1.4 (D+)
D-: J5.A7 (D-), J5.B7 (D-), U1.5 (D-)
DC_RS: FPC1.10 (DC/RS), R12.2, U4.24 (IO2)
DTR: Q2.2 (B), R5.2, U1.28 (~DTR)
EN: C8.1, Q1.3 (C), R8.2, SW2.1 (A), U4.3 (EN)
GND: C1.2, C2.2, C4.2, C5.2, C6.2, C7.2, C8.2, C9.2, C10.2, D3.1 (K), FPC1.5 (GND), FPC1.16 (GND), FPC1.17 (DB0), FPC1.18 (DB1), FPC1.19 (DB2), FPC1.20 (DB3), FPC1.21 (DB4), FPC1.22 (DB5), FPC1.23 (DB6), FPC1.24 (DB7), FPC1.25 (DB8), FPC1.26 (DB9), FPC1.27 (DB10), FPC1.28 (DB11), FPC1.29 (DB12), FPC1.30 (DB13), FPC1.31 (DB14), FPC1.32 (DB15), FPC1.37 (GND), FPC2.6, J2.5, J3.2, J4.4, J5.A1 (GND), J5.A12 (GND), J5.B1 (GND), J5.B12 (GND), LS1.2, Q4.2 (B), R2.2, R12.1, R15.2, R24.1, R25.1, Rprog1.2, SD1.6 (VSS), SD1.10 (SHIELD), SW1.2 (B), SW2.2 (B), SW3.1 (A), U1.3 (GND), U1.29 (GND), U3.2 (GND), U4.1 (GND), U4.15 (GND), U4.38 (GND), U4.39 (GND), U5.2 (VSS)
IO0: Q2.3 (C), R10.2, SW1.1 (A), U4.25 (IO0)
IO5: R23.2, U4.29 (IO5)
IO12: J2.7, U4.14 (IO12)
IO13: J2.9, U4.16 (IO13)
IO14: J2.11, U4.13 (IO14)
IO16: J2.13, U4.27 (IO16)
IO17: J2.14, U4.28 (IO17)
IO33: J2.2, U4.9 (IO33)
IO34: J2.1, U4.6 (IO34)
LDO_EN: SW3.2 (B), U3.3 (EN)
LED_K1: FPC1.34 (LED_K), R19.2
LED_K2: FPC1.35 (LED_K), R20.2
LED_K3: FPC1.36 (LED_K), R21.2
unnamed: D2.1 (K), JP3.1
unnamed: D3.2 (A), R22.2
unnamed: F1.2, J5.A4 (VBUS), J5.A9 (VBUS), J5.B4 (VBUS), J5.B9 (VBUS)
unnamed: J5.A5 (CC1), R24.2
unnamed: J5.B5 (CC2), R25.2
unnamed: JP1.2 (C), R18.1
unnamed: JP2.1, R22.1
unnamed: JP3.2, R13.1
unnamed: Q1.1 (E), R5.1
unnamed: Q2.1 (E), R6.1
unnamed: Q4.1 (E), R18.2
unnamed: Q4.3 (C), R19.1, R20.1, R21.1
unnamed: R3.2, U1.25 (RXD)
unnamed: R4.2, U1.26 (TXD)
unnamed: R13.2, U5.1 (STAT)
unnamed: Rprog1.1, U5.5 (PROG)
PIEZO: LS1.1, U4.11 (IO26)
RSTb: R1.2, U1.9 (~RSTb)
RTS: Q1.2 (B), R6.2, U1.24 (~RTS)
RXD0: R4.1, U4.34 (RXD0/IO3)
SCK: FPC1.11 (SCK), J2.8, SD1.5 (CLK), U4.30 (IO18)
SCL: FPC2.3, J2.4, J4.1, R11.2, R17.2, U4.36 (IO22)
SDA: FPC2.2, J2.3, J4.2, R7.2, R16.2, U4.33 (IO21)
SDI: FPC1.13 (SDI), J2.12, SD1.3 (CMD), U4.37 (IO23)
SDO: J2.10, SD1.7 (DAT0), U4.31 (IO19)
SD_CS: SD1.2 (CD/DAT3), U4.10 (IO25)
TFT_CS: FPC1.9 (CS), U4.23 (IO15)
TFT_LED: JP1.1 (A), U4.8 (IO32)
TFT_RESET: FPC1.15 (RESET), U4.26 (IO4)
TXD0: R3.1, U4.35 (TXD0/IO1)
VBUS: C1.1, C2.1, D1.2 (A), D2.2 (A), F1.1, Q3.1 (G), R2.1, TP1.1, U1.8 (VBUS), U5.4 (VDD)

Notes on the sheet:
Power and Filtering
LDO Enable Switch
Battery Charging
Battery Monitor
ESP32 WROOM
TFT FPC 40 Pin
Note: Pulling LDO_EN low disables everything, except battery charging.
Note: Charging Current (mA) = 1100(V) / Rprog (kΩ)
CTC FPC CONNECTOR
Speaker
Switches
I/O Breakout
C255335
NOTES: - LCSC PART# in italic. Starts with C.
Mounting Holes
SD Card
Stemma Connector
C262262
C473012
C250808
C91145
Note: R18, R19, and R20 t.b.d.
C96616
C150742
C92658
C160352
C11097
C455281
Auto Reset
C6568
USB to Serial + Auto Reset
TFT Backlight
C84004
USB C connector
C319148

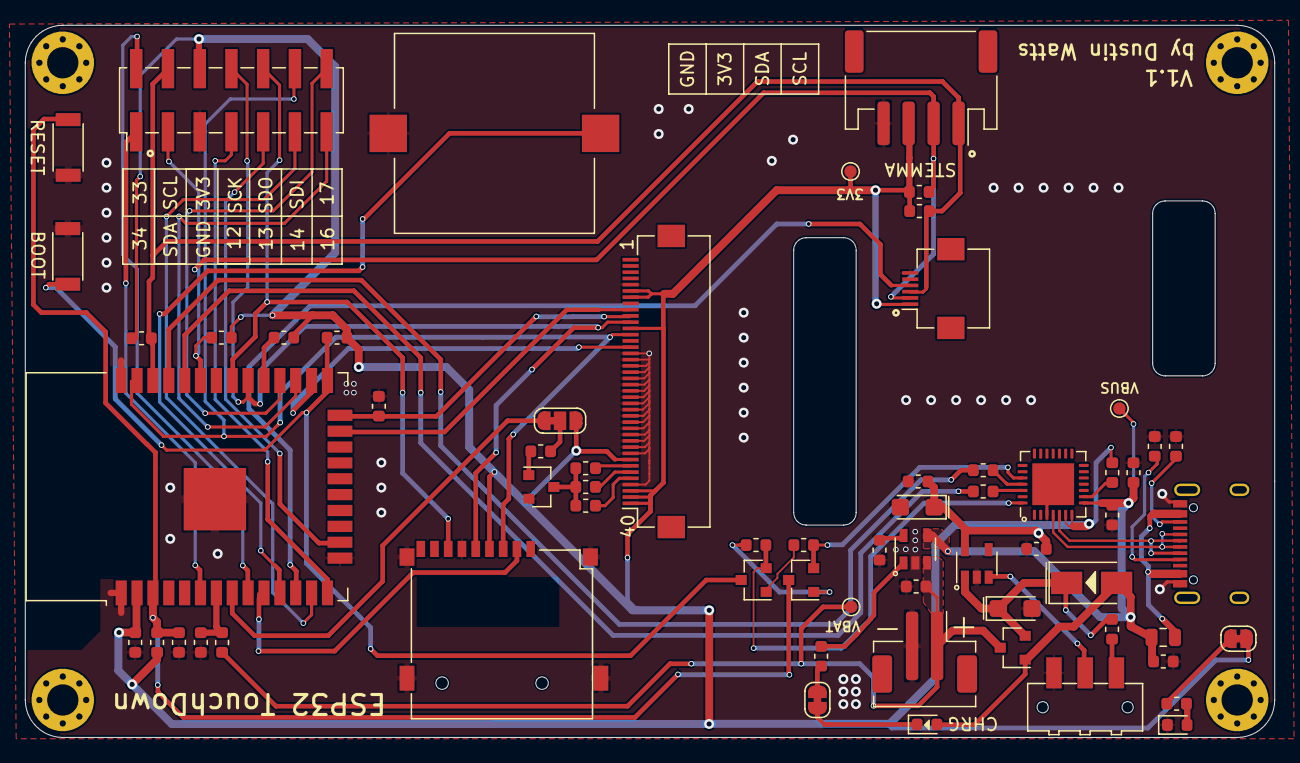
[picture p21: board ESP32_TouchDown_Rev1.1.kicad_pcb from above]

Board: 2 copper layers, 100.0 x 57.0 mm, 68 parts (0 on the bottom side), 56 nets.

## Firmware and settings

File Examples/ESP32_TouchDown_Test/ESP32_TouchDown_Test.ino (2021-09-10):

/* ESP32 TouchDown Test
 * by: Dustin Watts
 * date: 30-10-2020
 * 
 * This is the test used to check all new boards. It tests the TFT screen (SPI),
 * the FT6236 touch controller (I2C), WiFi, SPIFFS, BLE, UART, the battery voltage, 
 * the speaker, the SD card, and tests all the broken out pins.
 * 
 * These libraries need to be installed:
 * 
 * - ESP32-BLE-Keyboard forked from T-vk (https://github.com/DustinWatts/ESP32-BLE-Keyboard)
 * - FT6236 (https://github.com/DustinWatts/FT6236)
 * - TFT_eSPI (available through the Library Manager)
 * 
 * ! Don't forget to configure User_Setup.h in the TFT_eSPI library. You can use User_setup.h in "/TFT_eSPI Setup Example".
 * 
 * User_Setup.h configuration:
 * 
 * #define ILI9488_DRIVER 
 * 
 * #define TFT_MISO 19
 * #define TFT_MOSI 23
 * #define TFT_SCLK 18
 * #define TFT_CS   15  // Chip select control pin
 * #define TFT_DC    2  // Data Command control pin
 * #define TFT_RST   4 
 * 
 */

#include <FT6236.h>        // Capacitive Touch Controller Library
#include <WiFi.h>          // Wifi support
#include <WiFiClient.h>    // Wifi support
#include <BleKeyboard.h>   // BleKeyboard is used to communicate over BLE

#include "BLEDevice.h"     // Additional BLE functionaity
#include "BLEUtils.h"      // Additional BLE functionaity
#include "BLEBeacon.h"     // Additional BLE functionaity

#include "esp_bt_main.h"   // Additional BLE functionaity
#include "esp_bt_device.h" // Additional BLE functionaity

#include <pgmspace.h> // PROGMEM support header
#include "FS.h"       // File System header
#include "SD.h"       // SD Card header 

#include <TFT_eSPI.h> // The TFT_eSPI library

TFT_eSPI tft = TFT_eSPI();

char ssid[64] = "";           // <-- Your WIFI SSID
char password[64] = "";       // <-- Your WIFI PASSWORD

uint8_t sdSelectPin = 25;

byte red = 31;
byte green = 0;
byte blue = 0;
byte state = 0;
unsigned int colour = red << 11; // Colour order is RGB 5+6+5 bits each
 
bool initBluetooth()
{
  if (!btStart()) {
    Serial.println("Failed to initialize controller");
    return false;
  }
 
  if (esp_bluedroid_init() != ESP_OK) {
    Serial.println("Failed to initialize bluedroid");
    return false;
  }
 
  if (esp_bluedroid_enable() != ESP_OK) {
    Serial.println("Failed to enable bluedroid");
    return false;
  }

  return true;
 
}
 
void printDeviceAddress() {
 
  const uint8_t* point = esp_bt_dev_get_address();
 
  for (int i = 0; i < 6; i++) {
 
    char str[3];
 
    sprintf(str, "%02X", (int)point[i]);
    Serial.print(str);
    tft.print(str);
 
    if (i < 5){
      Serial.print(":");
      tft.print(":");
    }
 
  }
}

void readFile(fs::FS &fs, const char * path){
    Serial.printf("Reading file: %s\n", path);

    File file = fs.open(path);
    if(!file){
        Serial.println("Failed to open file for reading");
        return;
    }

    Serial.print("Read from file: ");
    while(file.available()){
        Serial.write(file.read());
    }
    file.close();
}

void writeFile(fs::FS &fs, const char * path, const char * message){
    Serial.printf("Writing file: %s\n", path);

    File file = fs.open(path, FILE_WRITE);
    if(!file){
        Serial.println("Failed to open file for writing");
        return;
    }
    if(file.print(message)){
        Serial.println("File written");
    } else {
        Serial.println("Write failed");
    }
    file.close();
}

void appendFile(fs::FS &fs, const char * path, const char * message){
    Serial.printf("Appending to file: %s\n", path);

    File file = fs.open(path, FILE_APPEND);
    if(!file){
        Serial.println("Failed to open file for appending");
        return;
    }
    if(file.print(message)){
        Serial.println("Message appended");
    } else {
        Serial.println("Append failed");
    }
    file.close();
}

FT6236 ts = FT6236();

BleKeyboard bleKeyboard("ESP32 TouchDown Test", "by Dustin Watts");

void setup() {
  
  // Use serial port
  Serial.begin(9600);
  Serial.println("");

  if (!SPIFFS.begin())
    {
      Serial.println("SPIFFS initialisation failed!");
      tft.println("SPIFFS initialisation failed!");
      while (1)
        yield(); // We stop here
    }
    Serial.println("SPIFFS initialised.");
    tft.println("SPIFFS initialised.");

  if (!SD.begin(sdSelectPin))
    {
      Serial.println("SD Card initialisation failed!");
      tft.println("SD Card initialisation failed!");
//      while (1)
//        yield(); // We stop here
    }
  
  Serial.println("SD Card initialised.");
  tft.println("SD Card initialised.");

  // Initialise TFT
  tft.init();
  tft.setTextColor(TFT_WHITE,TFT_BLACK);
  tft.setTextSize(2);

  // Set the rotation before we calibrate
  tft.setRotation(1);

  // Clear the screen
  tft.fillScreen(TFT_BLACK);

    if (!ts.begin(40)) { 
      Serial.println("Unable to start the capacitive touchscreen!");
      tft.println("Unable to start the capacitive touchscreen!");
    } 
    else { 
      Serial.println("Capacitive touch started!");
      tft.println("Capacitive touch started!");
      Serial.println("Touch the screen to start test.");
      tft.println("Touch the screen to start test.");
    }
    
  // Pin modes
  pinMode(33, OUTPUT);
  pinMode(12, OUTPUT);
  pinMode(13, OUTPUT);
  pinMode(14, OUTPUT);
  pinMode(16, OUTPUT);
  pinMode(17, OUTPUT);

  // Setup PWM channel for Piezo speaker
  ledcSetup(0, 500, 8);
  
}

void loop() {

  if (ts.touched()){

      tft.fillScreen(TFT_BLACK);
      Serial.println("Touch received, starting test...");
      tft.println("Touch received, starting test...");
      
      // Beep Beep  
      ledcAttachPin(26, 0);
      ledcWriteTone(0, 600);
      delay(150);
      ledcDetachPin(26);
      ledcWrite(0, 0);
    
      ledcAttachPin(26, 0);
      ledcWriteTone(0, 800);
      delay(150);
      ledcDetachPin(26);
      ledcWrite(0, 0);
    
      // Blink breakout header pins

      Serial.println("IOs on...");
      tft.println("IOs on...");
      
      digitalWrite(33, HIGH);
      delay(100);
      digitalWrite(12, HIGH);
      delay(100);
      digitalWrite(13, HIGH);
      delay(100);
      digitalWrite(14, HIGH);
      delay(100);
      digitalWrite(16, HIGH);
      delay(100);
      digitalWrite(17, HIGH);
      delay(100);

      delay(5000);

      Serial.println("IOs off...");
      tft.println("IOs off...");

      digitalWrite(33, LOW);
      delay(100);
      digitalWrite(12, LOW);
      delay(100);
      digitalWrite(13, LOW);
      delay(100);
      digitalWrite(14, LOW);
      delay(100);
      digitalWrite(16, LOW);
      delay(100);
      digitalWrite(17, LOW);
      delay(100);

      // TEST SD Card
      uint8_t cardType = SD.cardType();

      Serial.print("SD Card Type: ");
      tft.print("SD Card Type: ");
        if(cardType == CARD_MMC){
            Serial.println("MMC");
            tft.println("MMC");
        } else if(cardType == CARD_SD){
            Serial.println("SDSC");
            tft.println("SDSC");
        } else if(cardType == CARD_SDHC){
            Serial.println("SDHC");
            tft.println("SDHC");
        } else {
            Serial.println("UNKNOWN");
            tft.println("UNKNOWN");
        }
    
      uint64_t cardSize = SD.cardSize() / (1024 * 1024);
      Serial.printf("SD Card Size: %lluMB\n", cardSize);
      tft.printf("SD Card Size: %lluMB\n", cardSize);

      // Measure battery voltage
      uint16_t adc = analogRead(35);
      Serial.print("ADC VALUE = ");
      tft.print("ADC VALUE = ");
      Serial.println(adc);
      tft.println(adc);
      delay(1000);
      float voltage = adc * 1.782;
      Serial.print("Battery Voltage = ");
      tft.print("Battery Voltage = ");
      Serial.print(voltage / 1000);
      tft.print(voltage / 1000);
      Serial.println("V");
      tft.println("V");
      delay(1000);

      //Starting BLE
      Serial.println("Starting BLE...");
      tft.println("Starting BLE...");
      initBluetooth();
      delay(1000);
      bleKeyboard.begin();
      Serial.print("BLE Device Address: ");
      tft.print("BLE Device Address: ");
      printDeviceAddress();
      Serial.println("");
      tft.println("");
      delay(1000);
      
      //Starting WiFi
      Serial.println("Starting WiFi...");
      tft.println("Starting WiFi...");
      delay(1000);
      Serial.printf("Connecting to %s", ssid);
      tft.print("Connecting to ");
      tft.print(ssid);
      
      if (String(WiFi.SSID()) != String(ssid))
      {
        WiFi.mode(WIFI_STA);
        WiFi.begin(ssid, password);
        while (WiFi.status() != WL_CONNECTED)
        {
          delay(500);
          Serial.print(".");
  
        }
      }
      
      Serial.println("");
      tft.println("");
      Serial.print("Connected! IP address: ");
      tft.print("Connected! IP address: ");
      Serial.println(WiFi.localIP());
      tft.println(WiFi.localIP());
      delay(1000);

      Serial.println("Starting to draw pretty colours");
      tft.print("Starting to draw pretty colours");

      for(int i=0; i < 5; i++)
      {
        Serial.print(".");
        tft.print(".");  
        delay(500);
      }

      Serial.println(".");
      
      tft.fillScreen(TFT_BLACK);
      
      for(int i=0; i < 50; i++)
      {
        rainbow_fill();
      }

      tft.fillScreen(TFT_BLACK);
      tft.setCursor (0, 0);
      
      Serial.println("Drawing from SPIFFS");
      drawBmpSPIFFS("/thumbsup.bmp", 0, 0);

      delay(5000);

      Serial.println("Drawing from SD");
      drawBmpSD("/thumbsup.bmp", 0, 0);

      delay(5000);

      tft.fillScreen(TFT_BLACK);
      tft.setCursor (0, 0);
      
      Serial.println("Test successfully finished!");
      tft.println("Test successfully finished!");

      WiFi.mode(WIFI_OFF);
      WiFi.disconnect(true);
      
  }
  
}

// Fill screen with a rainbow pattern
void rainbow_fill()
{
  // The colours and state are not initialised so the start colour changes each time the funtion is called
  
  for (int i = 479; i > 0; i--) {
    // Draw a vertical line 1 pixel wide in the selected colour
    tft.drawFastHLine(0, i, tft.width(), colour); // in this example tft.width() returns the pixel width of the display
    // This is a "state machine" that ramps up/down the colour brightnesses in sequence
    switch (state) {
      case 0:
        green ++;
        if (green == 64) {
          green = 63;
          state = 1;
        }
        break;
      case 1:
        red--;
        if (red == 255) {
          red = 0;
          state = 2;
        }
        break;
      case 2:
        blue ++;
        if (blue == 32) {
          blue = 31;
          state = 3;
        }
        break;
      case 3:
        green --;
        if (green == 255) {
          green = 0;
          state = 4;
        }
        break;
      case 4:
        red ++;
        if (red == 32) {
          red = 31;
          state = 5;
        }
        break;
      case 5:
        blue --;
        if (blue == 255) {
          blue = 0;
          state = 0;
        }
        break;
    }
    colour = red << 11 | green << 5 | blue;
  }
}

void drawBmpSPIFFS(const char *filename, int16_t x, int16_t y)
{

  if ((x >= tft.width()) || (y >= tft.height()))
    return;

  fs::File bmpFS;

  bmpFS = SPIFFS.open(filename, "r");

  if (!bmpFS)
  {
    Serial.print("File not found");
    return;
  }

  uint32_t seekOffset;
  uint16_t w, h, row, col;
  uint8_t r, g, b;

  uint32_t startTime = millis();

  if (read16(bmpFS) == 0x4D42)
  {
    read32(bmpFS);
    read32(bmpFS);
    seekOffset = read32(bmpFS);
    read32(bmpFS);
    w = read32(bmpFS);
    h = read32(bmpFS);

    if ((read16(bmpFS) == 1) && (read16(bmpFS) == 24) && (read32(bmpFS) == 0))
    {
      y += h - 1;

      bool oldSwapBytes = tft.getSwapBytes();
      tft.setSwapBytes(true);
      bmpFS.seek(seekOffset);

      uint16_t padding = (4 - ((w * 3) & 3)) & 3;
      uint8_t lineBuffer[w * 3 + padding];

      for (row = 0; row < h; row++)
      {

        bmpFS.read(lineBuffer, sizeof(lineBuffer));
        uint8_t *bptr = lineBuffer;
        uint16_t *tptr = (uint16_t *)lineBuffer;
        // Convert 24 to 16 bit colours
        for (uint16_t col = 0; col < w; col++)
        {
          b = *bptr++;
          g = *bptr++;
          r = *bptr++;
          *tptr++ = ((r & 0xF8) << 8) | ((g & 0xFC) << 3) | (b >> 3);
        }

        // Push the pixel row to screen, pushImage will crop the line if needed
        // y is decremented as the BMP image is drawn bottom up
        tft.pushImage(x, y--, w, 1, (uint16_t *)lineBuffer);
      }
      tft.setSwapBytes(oldSwapBytes);
    }
    else
      Serial.println("[WARNING]: BMP format not recognized.");
  }
  bmpFS.close();
}

void drawBmpSD(const char *filename, int16_t x, int16_t y)
{

  if ((x >= tft.width()) || (y >= tft.height()))
    return;

  fs::File bmpFS;

  bmpFS = SD.open(filename, "r");

  if (!bmpFS)
  {
    Serial.print("File not found");
    return;
  }

  uint32_t seekOffset;
  uint16_t w, h, row, col;
  uint8_t r, g, b;

  uint32_t startTime = millis();

  if (read16(bmpFS) == 0x4D42)
  {
    read32(bmpFS);
    read32(bmpFS);
    seekOffset = read32(bmpFS);
    read32(bmpFS);
    w = read32(bmpFS);
    h = read32(bmpFS);

    if ((read16(bmpFS) == 1) && (read16(bmpFS) == 24) && (read32(bmpFS) == 0))
    {
      y += h - 1;

      bool oldSwapBytes = tft.getSwapBytes();
      tft.setSwapBytes(true);
      bmpFS.seek(seekOffset);

      uint16_t padding = (4 - ((w * 3) & 3)) & 3;
      uint8_t lineBuffer[w * 3 + padding];

      for (row = 0; row < h; row++)
      {

        bmpFS.read(lineBuffer, sizeof(lineBuffer));
        uint8_t *bptr = lineBuffer;
        uint16_t *tptr = (uint16_t *)lineBuffer;
        // Convert 24 to 16 bit colours
        for (uint16_t col = 0; col < w; col++)
        {
          b = *bptr++;
          g = *bptr++;
          r = *bptr++;
          *tptr++ = ((r & 0xF8) << 8) | ((g & 0xFC) << 3) | (b >> 3);
        }

        // Push the pixel row to screen, pushImage will crop the line if needed
        // y is decremented as the BMP image is drawn bottom up
        tft.pushImage(x, y--, w, 1, (uint16_t *)lineBuffer);
      }
      tft.setSwapBytes(oldSwapBytes);
    }
    else
      Serial.println("[WARNING]: BMP format not recognized.");
  }
  bmpFS.close();
}

uint16_t read16(fs::File &f)
{
  uint16_t result;
  ((uint8_t *)&result)[0] = f.read(); // LSB
  ((uint8_t *)&result)[1] = f.read(); // MSB
  return result;
}

uint32_t read32(fs::File &f)
{
  uint32_t result;
  ((uint8_t *)&result)[0] = f.read(); // LSB
  ((uint8_t *)&result)[1] = f.read();
  ((uint8_t *)&result)[2] = f.read();
  ((uint8_t *)&result)[3] = f.read(); // MSB
  return result;
}

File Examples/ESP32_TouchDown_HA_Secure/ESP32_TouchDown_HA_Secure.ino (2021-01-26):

/**
  Title: ESP32 TouchDown HA Secure
  Author: Dustin Watts
  Date: 01-01-2021

  A simple 4 by 3 matrix of buttons (called A through L) to show how you could control your Home Assistant by using their API.
  For this example you will need to have a Long Lives Access Token from HA. You will also need the IP address and port
  of your server. 

  This example uses a secure connection to an HA server. You will need the root certificate of the server. You'll need to convert this 
  to a multiline string. Basically, take the raw text of the certificate and add `"` at the beginning of each line and add `\n"`
  at the end of each line.

  HA expects a JSON object as payload. You can use ArduinoJson to create those objects, but in this exmaple I'm just creating the raw
  data myself. Make sure when you create the string to escape all double quotes! E.g. "{\"entity_id\":\"switch.simple_led_1\"}"

  This example is based on the examples that come with the TFT_eSPI library. Which includes the Adafruit GFX button handling class.

  These libraries need to be installed:
  
  - FT6236 (https://github.com/DustinWatts/FT6236)
  - TFT_eSPI (available through the Library Manager)

  ! Don't forget to configure User_Setup.h in the TFT_eSPI library. You can use User_setup.h in "/TFT_eSPI Setup Example".

*/

#include <TFT_eSPI.h> // The TFT_eSPI library
#include <WiFi.h> // Wifi support
#include <WiFiClientSecure.h>
#include <HTTPClient.h> 
#include <ESPmDNS.h> // mDNS functionality
#include <Wire.h>
#include <FT6236.h>

const char *ssid = " "; // <- SSID here
const char *password = " "; // <- Password here
const char *server = " "; // the IP address of your HA server here
uint16_t port = 443; // the port of your HA server here

// Place your Long Lived Access Token from HA here:
const char *authtoken = " ";

// Root Certificate of the server

const char* rootCACertificate = \
"-----BEGIN CERTIFICATE-----\n"
"MIIFFjCCAv6gAwIBAgIRAJErCErPDBinU/bWLiWnX1owDQYJKoZIhvcNAQELBQAw\n"
"TzELMAkGA1UEBhMCVVMxKTAnBgNVBAoTIEludGVybmV0IFNlY3VyaXR5IFJlc2Vh\n"
"cmNoIEdyb3VwMRUwEwYDVQQDEwxJU1JHIFJvb3QgWDEwHhcNMjAwOTA0MDAwMDAw\n"
"WhcNMjUwOTE1MTYwMDAwWjAyMQswCQYDVQQGEwJVUzEWMBQGA1UEChMNTGV0J3Mg\n"
"RW5jcnlwdDELMAkGA1UEAxMCUjMwggEiMA0GCSqGSIb3DQEBAQUAA4IBDwAwggEK\n"
"AoIBAQC7AhUozPaglNMPEuyNVZLD+ILxmaZ6QoinXSaqtSu5xUyxr45r+XXIo9cP\n"
"R5QUVTVXjJ6oojkZ9YI8QqlObvU7wy7bjcCwXPNZOOftz2nwWgsbvsCUJCWH+jdx\n"
"sxPnHKzhm+/b5DtFUkWWqcFTzjTIUu61ru2P3mBw4qVUq7ZtDpelQDRrK9O8Zutm\n"
"NHz6a4uPVymZ+DAXXbpyb/uBxa3Shlg9F8fnCbvxK/eG3MHacV3URuPMrSXBiLxg\n"
"Z3Vms/EY96Jc5lP/Ooi2R6X/ExjqmAl3P51T+c8B5fWmcBcUr2Ok/5mzk53cU6cG\n"
"/kiFHaFpriV1uxPMUgP17VGhi9sVAgMBAAGjggEIMIIBBDAOBgNVHQ8BAf8EBAMC\n"
"AYYwHQYDVR0lBBYwFAYIKwYBBQUHAwIGCCsGAQUFBwMBMBIGA1UdEwEB/wQIMAYB\n"
"Af8CAQAwHQYDVR0OBBYEFBQusxe3WFbLrlAJQOYfr52LFMLGMB8GA1UdIwQYMBaA\n"
"FHm0WeZ7tuXkAXOACIjIGlj26ZtuMDIGCCsGAQUFBwEBBCYwJDAiBggrBgEFBQcw\n"
"AoYWaHR0cDovL3gxLmkubGVuY3Iub3JnLzAnBgNVHR8EIDAeMBygGqAYhhZodHRw\n"
"Oi8veDEuYy5sZW5jci5vcmcvMCIGA1UdIAQbMBkwCAYGZ4EMAQIBMA0GCysGAQQB\n"
"gt8TAQEBMA0GCSqGSIb3DQEBCwUAA4ICAQCFyk5HPqP3hUSFvNVneLKYY611TR6W\n"
"PTNlclQtgaDqw+34IL9fzLdwALduO/ZelN7kIJ+m74uyA+eitRY8kc607TkC53wl\n"
"ikfmZW4/RvTZ8M6UK+5UzhK8jCdLuMGYL6KvzXGRSgi3yLgjewQtCPkIVz6D2QQz\n"
"CkcheAmCJ8MqyJu5zlzyZMjAvnnAT45tRAxekrsu94sQ4egdRCnbWSDtY7kh+BIm\n"
"lJNXoB1lBMEKIq4QDUOXoRgffuDghje1WrG9ML+Hbisq/yFOGwXD9RiX8F6sw6W4\n"
"avAuvDszue5L3sz85K+EC4Y/wFVDNvZo4TYXao6Z0f+lQKc0t8DQYzk1OXVu8rp2\n"
"yJMC6alLbBfODALZvYH7n7do1AZls4I9d1P4jnkDrQoxB3UqQ9hVl3LEKQ73xF1O\n"
"yK5GhDDX8oVfGKF5u+decIsH4YaTw7mP3GFxJSqv3+0lUFJoi5Lc5da149p90Ids\n"
"hCExroL1+7mryIkXPeFM5TgO9r0rvZaBFOvV2z0gp35Z0+L4WPlbuEjN/lxPFin+\n"
"HlUjr8gRsI3qfJOQFy/9rKIJR0Y/8Omwt/8oTWgy1mdeHmmjk7j1nYsvC9JSQ6Zv\n"
"MldlTTKB3zhThV1+XWYp6rjd5JW1zbVWEkLNxE7GJThEUG3szgBVGP7pSWTUTsqX\n"
"nLRbwHOoq7hHwg==\n"
"-----END CERTIFICATE-----";

// Keypad start position, key sizes and spacing
#define KEY_W 95 // Width and height
#define KEY_H 95
#define KEY_SPACING_X 20 // X and Y gap
#define KEY_SPACING_Y 10

#define KEY_X (KEY_W/2) + KEY_SPACING_X // Centre of key
#define KEY_Y (KEY_H/2) + KEY_SPACING_Y 

#define KEY_TEXTSIZE 3   // Font size multiplier

#define LABEL1_FONT &FreeSansOblique12pt7b // Key label font

FT6236 ts = FT6236();
TFT_eSPI tft = TFT_eSPI();

// Creating the labels for the buttons
char keyLabel[12][2] = {"A", "B", "C", "D", "E", "F", "G", "H", "I", "J", "K", "L"};

// Setting the colour for each button
uint16_t keyColor[12] = {TFT_BLUE, TFT_RED, TFT_GREEN, TFT_NAVY, 
                         TFT_MAROON, TFT_MAGENTA, TFT_ORANGE, TFT_SKYBLUE, 
                         TFT_PURPLE, TFT_CYAN, TFT_PINK, TFT_DARKCYAN
                        };

TFT_eSPI_Button key[12];
                        
void setup() {
  
  Serial.begin(9600);
  Serial.println("");

  Serial.printf("Connecting to %s", ssid);
    WiFi.mode(WIFI_STA);
    WiFi.begin(ssid, password);
    while (WiFi.status() != WL_CONNECTED)
    {
      delay(500);
      Serial.print(".");
    }
    Serial.println("");
    Serial.print("Connected! IP address: ");
    Serial.println(WiFi.localIP());

  // Initialise the touchcontroller
  ts.begin(40);

  // Initialise the TFT screen
  tft.init();

  // Set the rotation before we calibrate
  tft.setRotation(1);

  // Clear the screen
  tft.fillScreen(TFT_BLACK);

  // Draw keypad
  drawKeypad();

}

void loop() {

  uint16_t t_x = 0, t_y = 0; // To store the touch coordinates
  boolean pressed = false;
  
  if (ts.touched())
    {
      
      // Retrieve a point
      TS_Point p = ts.getPoint();

      //Flip things around so it matches our screen rotation
      p.x = map(p.x, 40, 280, 320, 0);
      t_y = p.x;
      t_x = p.y;

      pressed = true;
    }

  // Check if any key coordinate boxes contain the touch coordinates
  for (uint8_t b = 0; b < 12; b++) {
    if (pressed && key[b].contains(t_x, t_y)) {
      key[b].press(true);  // tell the button it is pressed
    } else {
      key[b].press(false);  // tell the button it is NOT pressed
    }
  }

  // Check if any key has changed state
  for (uint8_t b = 0; b < 12; b++) {

    if (key[b].justReleased()) key[b].drawButton();     // draw normal

    if (key[b].justPressed()) 
    {
      key[b].drawButton(true);  // draw invert
      buttonpress(b);
    }
  }

}
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

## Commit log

2020-12-11 Revision 1
    [ESP32_TFT-B_Cu.gbr, ESP32_TFT-B_Paste.gbr, ESP32_TFT-B_SilkS.gbr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]
2021-01-01 Revision 1
    Updated schematic with LCSC part numbers and added extra examples.
2021-01-01 Revision 1
    Update schematic PDF filename.
2021-01-01 Revision 1
    Update KICAD project.
    [ESP32_TouchDown.sch]
2021-01-28 Created Case .stl files
    [ESP32_TouchDown_Back_Battery.stl, ESP32_TouchDown_Back_FTD.stl, ESP32_TouchDown_Back_Flush.stl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]
2021-01-30 Added 30° angle FTD style back
    [ESP32_TouchDown_Back_FTD_30.stl]
2021-02-16 whoops missed a spelling misstake.
    😨
2021-02-16 Update with new images and updated BOM
    [ESP32_TouchDown_BOM.ods]
2021-02-17 Update README.md
    couple of minor spelling and grammar fixes
2021-03-17 Added 3D model
    Added .f3d, .obj and .step.
    [ESP32_TouchDown_Model.f3d]
2021-05-20 Updated 3D models
    The height of the TFT screen was incorrect. Was 3.1mm, should be 4.1mm.
    [ESP32_TouchDown_Model.f3d]
2021-09-10 Added ArduinoOSC example
    An example showing how to use ArduinoOSC to display cues on the ESP32 TouchDown.
2022-05-06 Hardware Rev1.1
    Added KiCad project, schematics, board and gerbers for Rev1.1, see changelog
    [ESP32_TouchDown.sch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]
2022-05-08 Added V1.1 Datasheets, update BOM
    Updated the BOM with alternate parts. Some of them used on V1.1. Also added the datasheets for those parts.
    [ESP32_TouchDown_BOM.ods]
2022-05-29 Remove Pre-Loaded_Sketch
    The Pre-Loaded_Sketch is deprecated because all ESP32 TouchDowns come pre-loaded with FreeTouchDeck.
2022-05-29 Add changelog.txt, update README.md
    Added changelog.txt describing changes since the board version is now V1.1. Also updated the README.md with changes from the changelog.
2023-02-14 Just some housekeeping
    Removed boards.txt (this was nonsense) and renamed `changelog.txt` changelog V1 to V1.1`.
2023-02-14 Update places to buy
    The ESP32 TouchDown is also available from lectronz.com
2023-03-09 Added .f3z file
    For modifying the case in Fusion360.
2023-04-18 Removed #define TFT_BACKLIGHT_ON HIGH
    This interferes with backlight dimming.
    [User_Setup.h]
2023-10-01 Added Grid Front for Case
    Added Grid Front for Case.
    [ESP32_TouchDown_Front_Grid.stl]
2023-10-03 Reworked the case grid
    [ESP32_TouchDown_Front_Grid.stl]
